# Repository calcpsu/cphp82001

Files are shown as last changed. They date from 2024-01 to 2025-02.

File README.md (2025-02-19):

# CalcPack HP 82001

A Li-Po battery replacement design for HP35/HP45/HP55/HP65/HP67 calculators. The original batteries had ~ 500mAh capacity, while modern Ni-MH replacements are typically ~1500mAh.

Li-Po has the advantage of far reduced self-discharge in comparison to Ni-MH, which is an advantage for an intermittently-used device. Even with similar mAh capacity, we can expect longer battery life.

Ni-MH / Ni-CD batteries are notorious for leaking. While Lithium Ion batteries are notorious for self-immolation, a well protected Li-Po battery (particularly in a low current application like this) should be able to be made very safe.

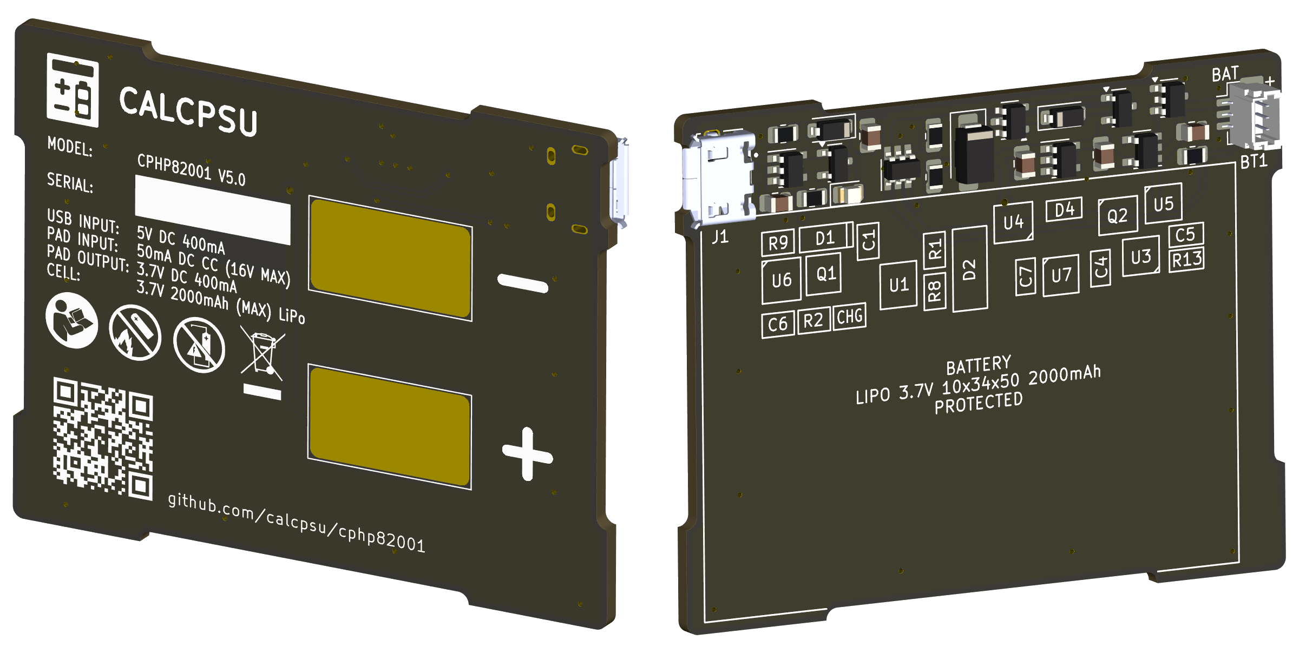
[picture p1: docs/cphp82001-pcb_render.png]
Render of calcpack PCB


## Features / design goals:
- Fit into existing compartment with no modifications
- Similar or ideally exceed capacity of standard Ni-Cd or Ni-MH 3xAA types (1200~2200mAh)
- Dual charge - USB (externally) or in-place using original HP charger
- Battery charge control and protection
- Maximise battery life:
    - Minimise Iq to maximise time between charges (shelf time)
    - Minimise voltage drop / series resistance of circuits to maximise run time
    - Optimise Vout to minimise calculator power consumption

## References 
This has been inspired by the below reference projects:
 - https://www.edn.com/classic-hp-35-calculator-comes-back-to-life/
   - GOOD: Regulated (see reasoning in the article, and discussion below)
   - BAD: Has no charging circuit / must remove to charge
   - BAD: Cannot connect HP charger (would cause dangerous overcharge condition; best case trip battery OC protection)
 - https://hackaday.io/project/175815-classic-hp-calculator-lipo-battery-pack
   - GOOD: Has on-board charge controller
   - BAD: Has no regulation
   - GOOD: Can connect HP charger, but
   - BAD: Unable to charge from HP charger / must remove to charge

## Key Components
If you're looking for a full BOM, please check the main files.
A digikey list is provided here for convenience (no guarantees!): [calcpsu cphp82001](https://www.digikey.com.au/en/mylists/list/Z6K09H5IB0)
 - Battery:
     - 10x34x50mm lipo pouch cell. These also include a DW01A/FS8205 protection circuit.
 - Charge controller: [BQ21040](https://www.ti.com/lit/ds/symlink/bq21040.pdf)
     - Wide voltage input range (over voltage protected)
     - Clever voltage foldback mode (which will help with constant current supply charging)
     - Variable current setting
     - Safety timer (10h) and 10% termination current
 - OPTION 1: Regulator: [TLV75801](https://www.ti.com/lit/ds/symlink/tlv758p.pdf)
     - Ultra low dropout (~30mV)
     - 500mA current limited (enough for HP67 card read/write at ~400mA for a few seconds)
     - Very low Iq for a regulator (25uA at idle, assuming Vb > Vo; only 400uA or so at full current)
     - Note: option eliminated as of REV5; if you're really keen for a regulated version please to check out rev4.
 - OPTION 2: Current Limiter: [MCP380SNT](https://www.onsemi.com/pdf/datasheet/ncp380-d.pdf)
     - Designed as a USB input current limiter, also works for LiPo cell voltage range
     - 800mA limiting, short circuit protection
     - Provides the similar current limiting capability as the TLV75801 with minimal additional quiescent current; allows retaining this function/protection in case of an unregulated option.
 - Output protection diode: [MAX40203](https://www.analog.com/media/en/technical-documentation/data-sheets/MAX40203.pdf)
     - Low voltage drop (~40mV) ideal diode
     - Low leakage and low Iq (<0.5uA)
 - Undervoltage protection: [APX809S-31SA](https://www.diodes.com/assets/Datasheets/APX809S-810S.pdf)
     - Pre-set with 3.1V threshold
     - Output used to shutdown regulator, shutting off load and vastly reducing Iq
     - Actual protective disconnection of battery done at ~2.5V by battery pack protection circuit (typically DW01A/FS8205)
 - Input overvoltage protection: [NCP360SNT](https://www.onsemi.com/pdf/datasheet/ncp360-d.pdf)
     - Cuts off USB input for overvoltage condition (note that 2x rated voltage is required by compliance test standard EN38.3 T.7, required for transport of lipo batteries in USA/EU).
     - Input via pads does not require OVP - it can tolerate the required 22v/100mA required condition.

## Function Description
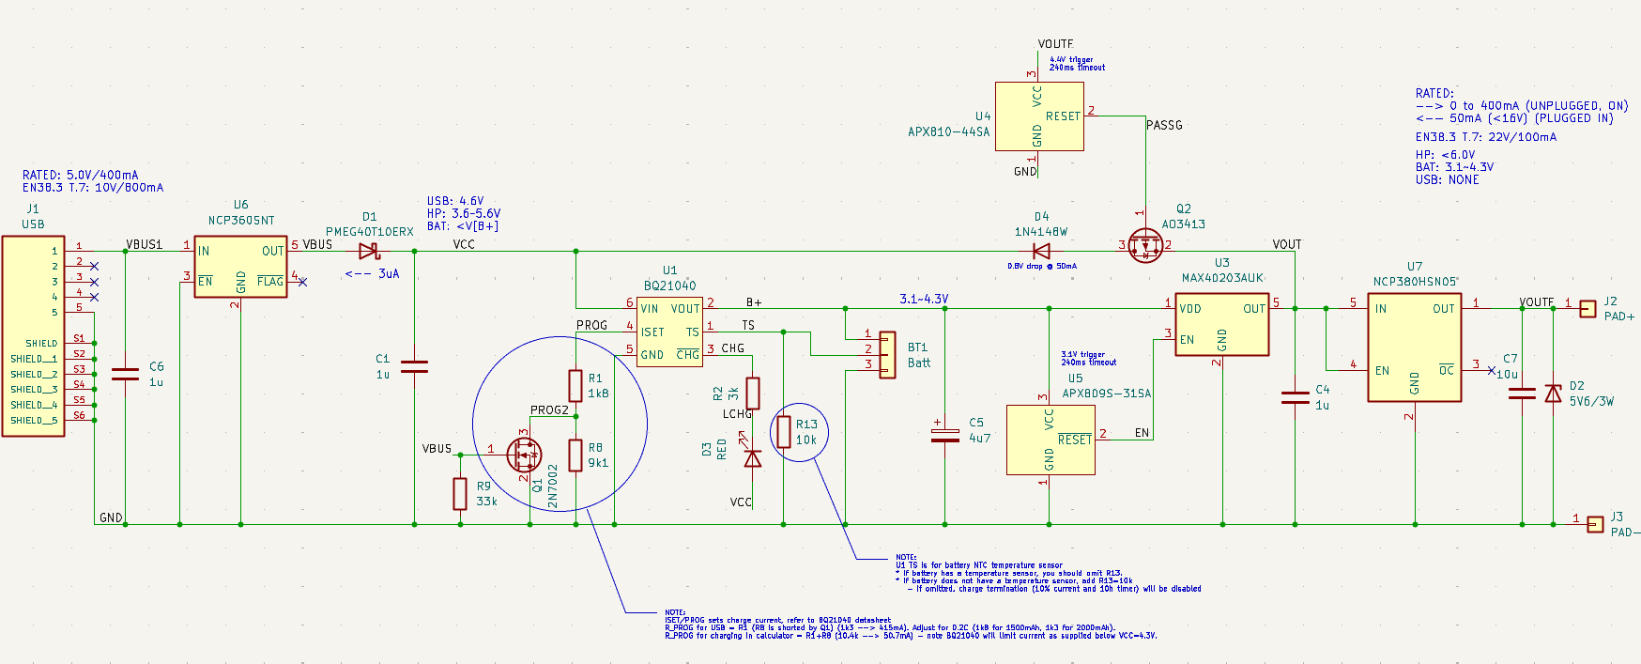
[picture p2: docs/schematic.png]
Block diagram of battery

### Discharging, calculator on:
 - B+ supplies cell voltage via current limiting IC
 - Output delivered to calculator via ideal diode U3
 - Vout at 3.8V is below threshold for U4 (4.4V), Q2 is off and VCC is 0V (charging IC shutdown completely)
### Charging, USB:
 - VBUS supplies VCC via U6 and D1
 - Presence of VBUS pulls prog down via Q1, charge controller now charges battery at higher current (0.2C target)
 - Physically not possible to do inside the calculator, can assume calculator is not connected during charging.
   - Although, body diode of Q2 and U3 would enable effective load sharing in this case, with output at about 4V (still well within acceptable limits for the calculator). This could be used for a future alternative in-system charging connection (e.g. a modified charging circuit, wireless charging, etc.)
### Charging, HP charger:
 - HP charger supplies 50mA constant current, up to 16V (!!). With the original NiCads, these acted as a voltage clamp (float charge about 1.43V/cell = 4.3V) - we need to replace this function.
    - With no charging current, voltage Vout rises until U3 switches off.
    - Will continue to rise until clamped by D2 (this should be low enough to protect HP65/67 sense chip from harm with extended application, but too low will result in excessive Iq as the voltage nears the zener's knee). Reviewing available documents, 4.3V is definitely OK, 6.25V might be survivable (as this is Vss normally). I have tested with 5.6V zener, and this has shown no negative impact to any calculators (particualrly the HP-67, where the sense chip sees this voltage, albeit when off).
    - Exceeding 4.4V for 240ms, U4 activates and connects Vout to Vcc via Q2 and D4.
    - D4 ensures that U1 throttles current (Vcc below 4.3V) before U4 cuts off supply (VOUTF 4.4V), maximising utilisation of limited constant current supply. See further explanation in [issue #5](https://github.com/calcpsu/cphp82001/issues/5).
    - U1 begins charge cycle, delivering up to 50mA to battery.
    - On charge termination, VCC current is minimal (10's of uA), all 50mA will be running through D2 (~0.25W power; using biggest one I can fit to keep temperature down). Voltage will be at the zener voltage (5.6V).
 - HP35/45/55 calculators do not draw current when on - supplied separately by HP AC adapter, the calculator supply is physically disconnected from the charging circuit.
 - HP65/67 with card reader: card reader may draw from battery supply. The sense chip is connected to the battery continuously, and will see up to the 5.6V float voltage. In case the calculator is operated and this draws current, the CC supply voltage will drop until U4 shuts off current to the charge circuit, resetting the charge cycle. When VOUT drops below B+, U3 activates, and card reader is powered from the current limiter (B+). As the AC adapter is not sufficient to run the card reader, this is the least worst outcome available.
### Battery Exhausted:
 - HP35 shows low battery (decimal points) indication at V+ of 3.50V.
   - This represents about 6-7% charge state of LiPo
   - User may switch off and recharge now...
 - HP67 will show indicator at about 3.60V; similar to above but a little more margin.
 - HP35 will cease to function at ~3.25V, still draws ~75mA
   - User probably should switch off and recharge now...
 - U4 protects battery at VB+ = 3.1V, by disabling the regulator or current limiting IC. Iq should be ~10uA.
 - If left for a _really_ long time, VB+ may reduce to 2.5V, which should trigger battery pack protection circuit and fully disconnect the battery. Plugging in (turning on charge controller, which will do a battery detection routine and reset the protection circuit) will reset.

## Assembly Notes ##

Refer to the schematic for details. The following notes are worth considering if building your own:
* The design up to v4 allows either regulated or unregulated option. From v5, only unregulated is supported (and recommended, see below).
  - For regulated (best for HP35), U2 regulator provides regulation and current limiting - U7 is not required and can be omitted and bypassed.
  - For unregulated (best for all later types), U2 is omitted and bypassed, and U7 is added to provide current limiting
* Digikey list is [here](https://www.digikey.com.au/en/mylists/list/Z6K09H5IB0)
* A 3-pin JST-SH (1.0mm pitch) connector is used for the battery. 1=pos, 2=temp, 3=neg
  - R13 is in parallel with TS pin NTC thermistor. If the battery does not a provide NTC thermistor (white wire, 3 pin connector), leave pin2 open and install R13=10k.
  - Note datasheet indicates 237k resistor prevents timer disable mode, but this also prevents charging without thermistor
    
| R13 | Battery With Temperature Sensor | Battery Without Temperature Sensor |
| --- | --- | --- |
| Omit | 🟢 10% Current Charge Termination <br> 🟢 10h Charge Timeout | 🔴 10% Current Charge Termination <br> 🔴 10h Charge Timeout |
| 10k  | ⚠️ Will not charge T>25C <br> ⚠️ Will charge T<0C  | 🟢 10% Current Charge Termination <br> 🟢  charge timeout |

* Two case sizes are provided:
    * 8mm suits 8mm thick batteries (1500mAh)
    * 10mm suits 10mm thick batteries (2000mAh), but it has been noted this can be a tight fit in some calculators
* Variants of each case, with and without an LED hole, are provided. If you 3D print with a transluscent material, the hole is not needed!

## Notes on optimisation:

Addition of a series regulator is not an immediately obvious means to maximise efficiency. I've measured the HP-35 increases current consumption as voltage rises (this is most likely a result of the way the LEDs are driven with fixed-duty inductive energy, this appears as brighter leds). Even accounting for the linear loss and Iq of the regulator circuit, total power consumption decreases as the regulator voltage decreases (down to about 3.6V, the minimum to operate the calculator reliably). The newer models (HP-45, HP-67) do the opposite - the current drops as the voltage increases, which indicates a more typical profile for a switchmode converter. The HP-67 has a card reader with a motor; this draws around 400mA when reading/writing a card, direct from battery. To allow for a little drop in the system, the regulator voltage needs to be a touch higher (looks like about 3.8V works consistently).

### Why not a switching regulator?

In theory, replacing the series linear regulator with a switching regulator may allow use of the battery capacity right down to 3.1V, and more efficiently use the currently wasted energy of the full battery (VB+ > 3.78V) currently being dissipated by the linear reg.

I've investigated using a MIC2250 step-up regulator, which has a surprisingly low Iq (55uA, not switching), and could provide a consistent output voltage right down to the end of the battery capacity (Vb=3.0V). At the currents needed, this can be around 87% efficient. This would provide a consistent voltage right up until shutdown. While this might be good particularly for the HP-67 card reader, it has the disadvantage of skipping the calculator's built-in low battery indication - the power supply unit would completely shutdown without any warning with a low battery.

### Model of 3 options

I've done a simulation of the 3 options:

  1. No regulator (default - calculator supplied with battery voltage via MAX40203 diode)
  2. Linear regulator (TLV75801, set to 3.80V)
  3. Switchmode step-up regulator (MIC2250, set to 3.80V also)

For each, the model calculates the change in output voltages given the battery state, calculator and power supply current draw, and iterates until the battery (2000mAh) is exhausted. The calculator load is measured from 3 sample calculators (HP-35, HP-45 and HP-67), reflecting the calculator being left on in the default display ("0." or "0.00" depending on the model), and accounts for the changing current with changing supply voltage. Results are shown below.

In summary, a regulated design gains a slight advantage in run time for the HP-35, while slightly reducing run time for HP-45 and HP-67. The switchmode design is actually best for the current-hungry HP-67, but not by a significant amount, and at the cost of higher quiescent current (shortening standby time significantly).

In conclusion, the regulated design provides a slight advantage for the HP-35 based on this model, however the unregulated design (with addition of necessary output short-circuit protection / current limiter) can be expected to be ideal for other models. Prototype testing with rev 3.5 showed the unregulated design works well in all the calculators, and the regulated design had noticeably faster self-discharge in practice, particularly as the quiescent current is larger than anticipated in dropout mode. As such, further designs have eliminated the regulator in favour of improved board layout and ease of use.

#### Results summary (t in hours)
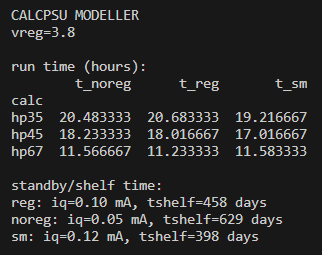
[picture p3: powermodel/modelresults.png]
Image of power model results

#### HP-35
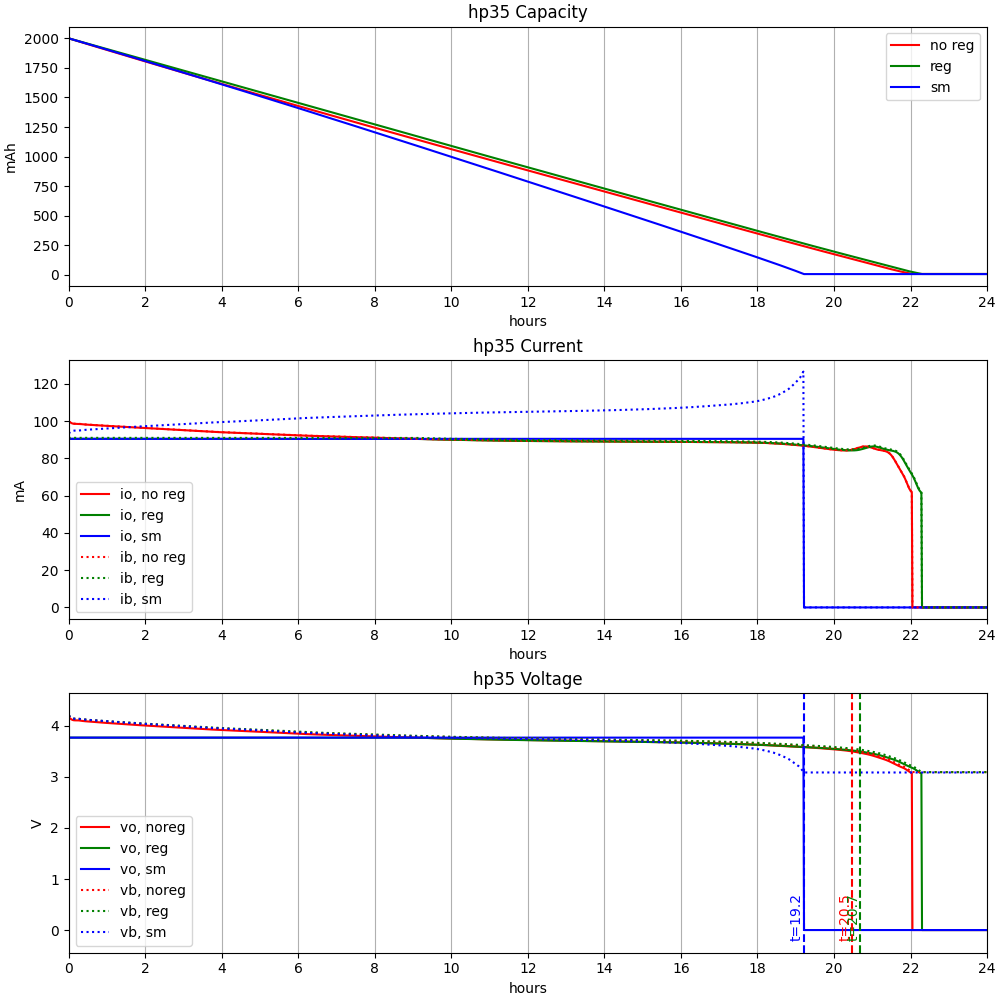
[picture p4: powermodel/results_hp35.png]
Image of power model results

#### HP-45
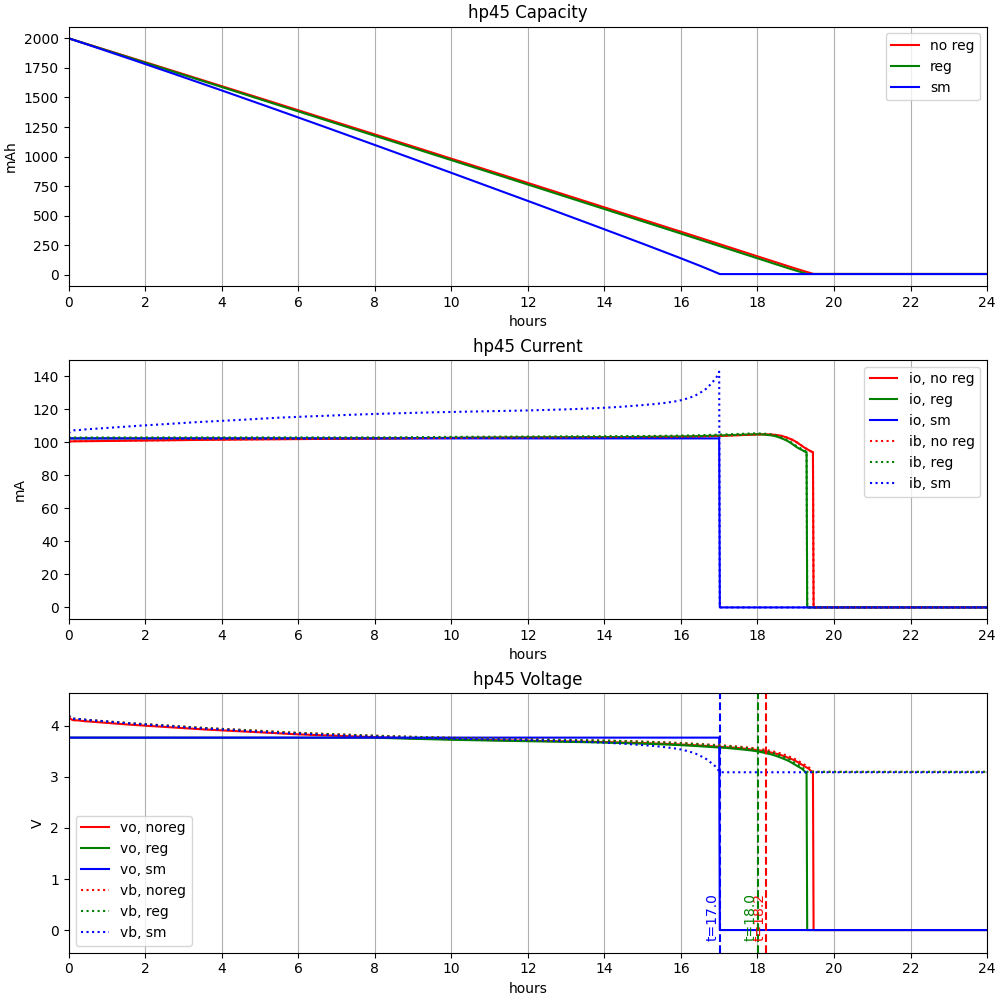
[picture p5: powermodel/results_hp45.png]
Image of power model results

#### HP-67
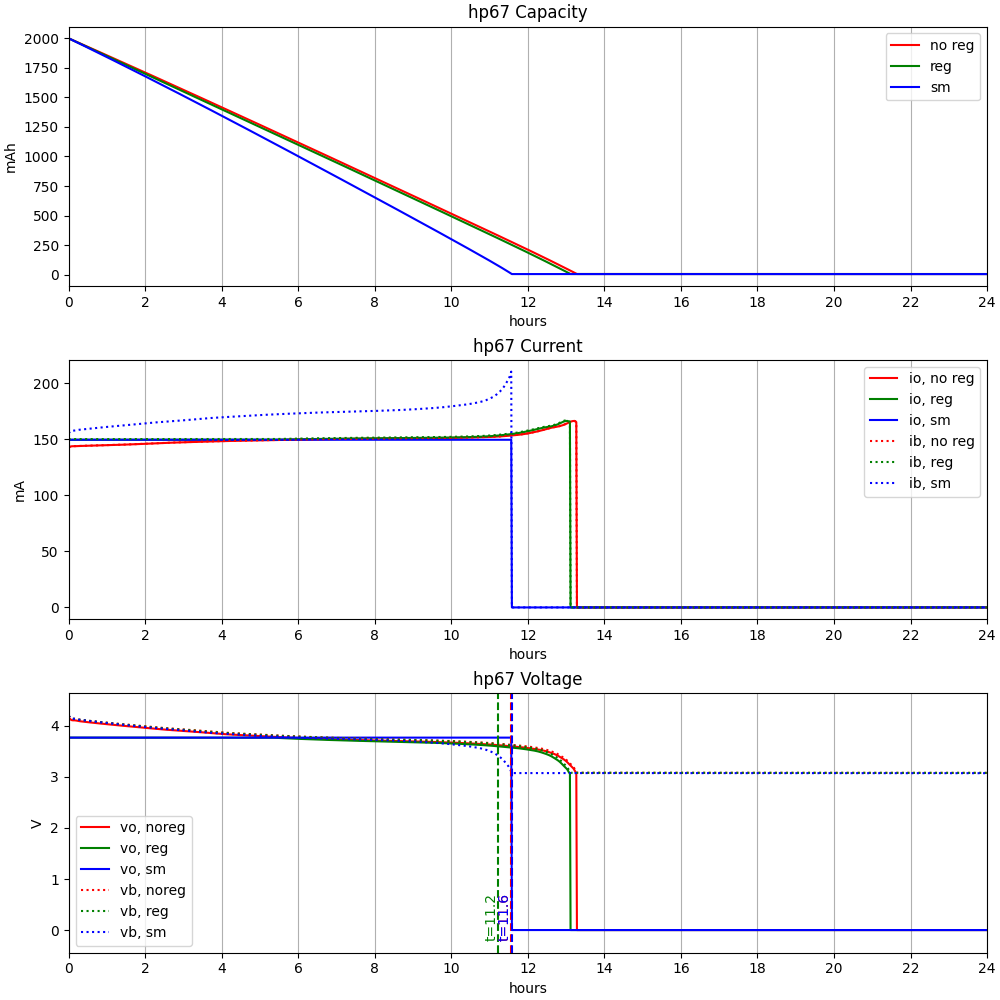
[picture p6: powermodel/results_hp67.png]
Image of power model results


## Community Builds ##
Built one? Send me some pics and I'll share here!
### [Milo van der Zee](https://github.com/MilovdZee) ###
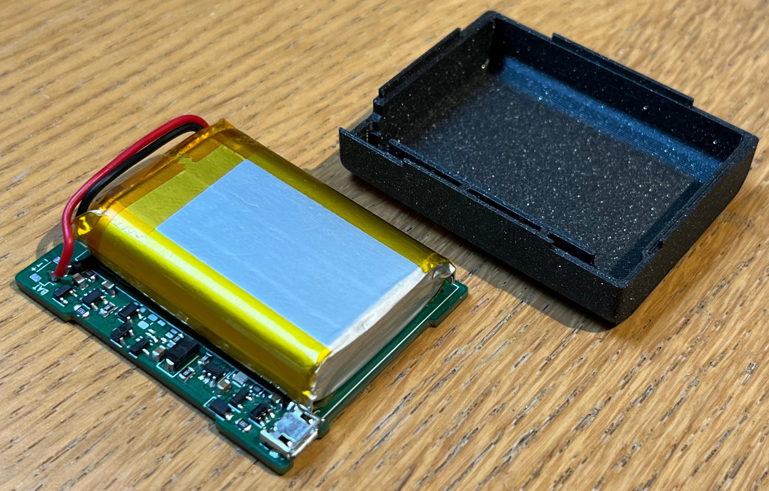
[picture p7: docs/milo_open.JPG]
Photo of build by Milo van der Zee


## License

This work is licensed under a
[Creative Commons Attribution-NonCommercial-ShareAlike 4.0 International License][cc-by-nc-sa].

[][cc-by-nc-sa]

[cc-by-nc-sa]: http://creativecommons.org/licenses/by-nc-sa/4.0/
[cc-by-nc-sa-image]: https://licensebuttons.net/l/by-nc-sa/4.0/88x31.png
[cc-by-nc-sa-shield]: https://img.shields.io/badge/License-CC%20BY--NC--SA%204.0-lightgrey.svg

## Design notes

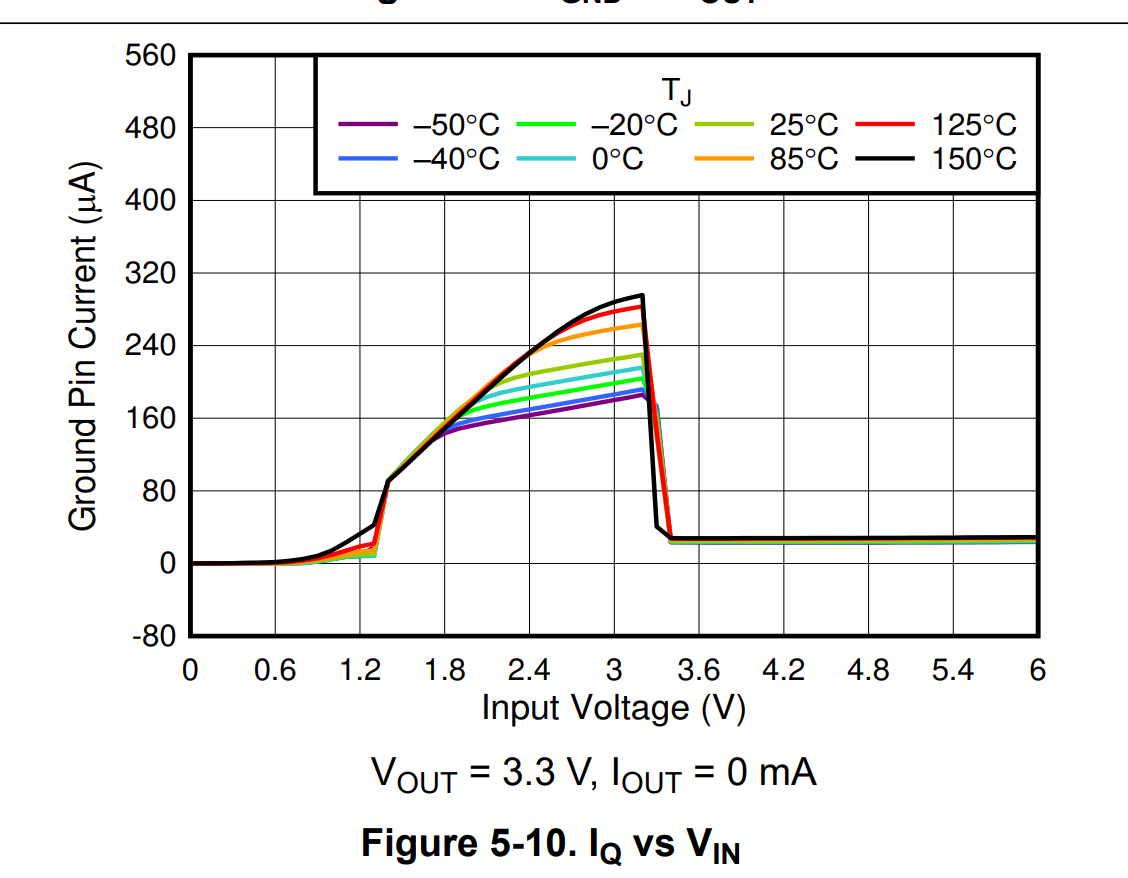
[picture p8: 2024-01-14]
powermodel/tlv75801_iq_3v3.png

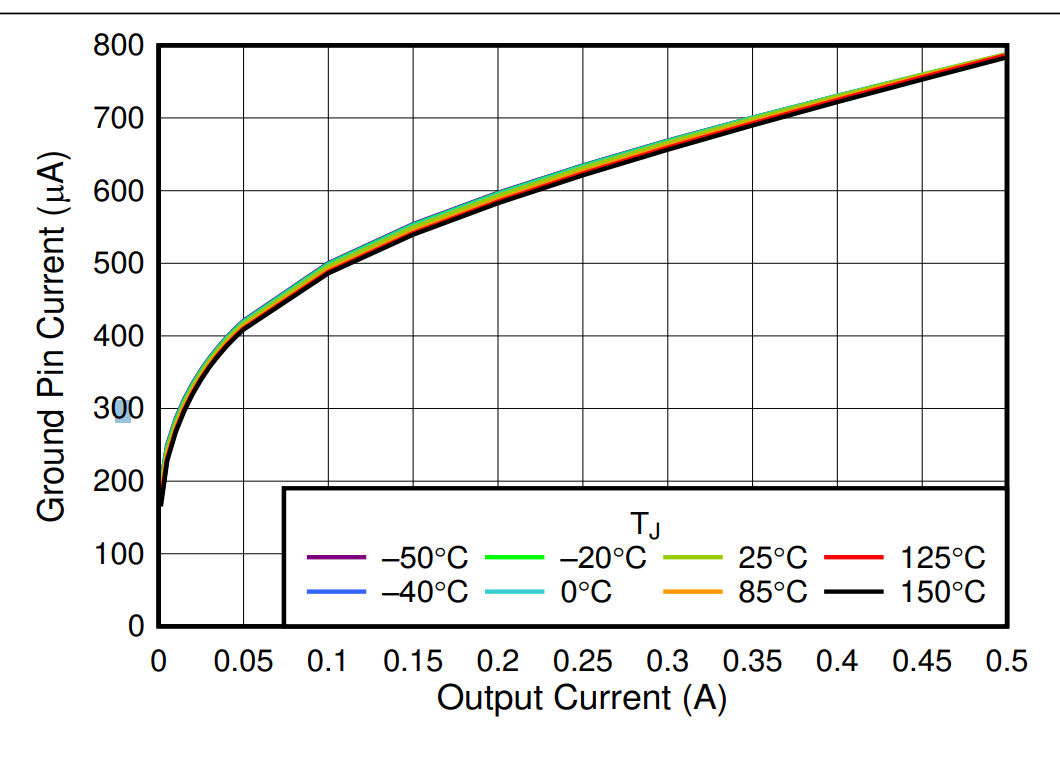
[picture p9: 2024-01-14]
powermodel/tlv75801_ignd.png

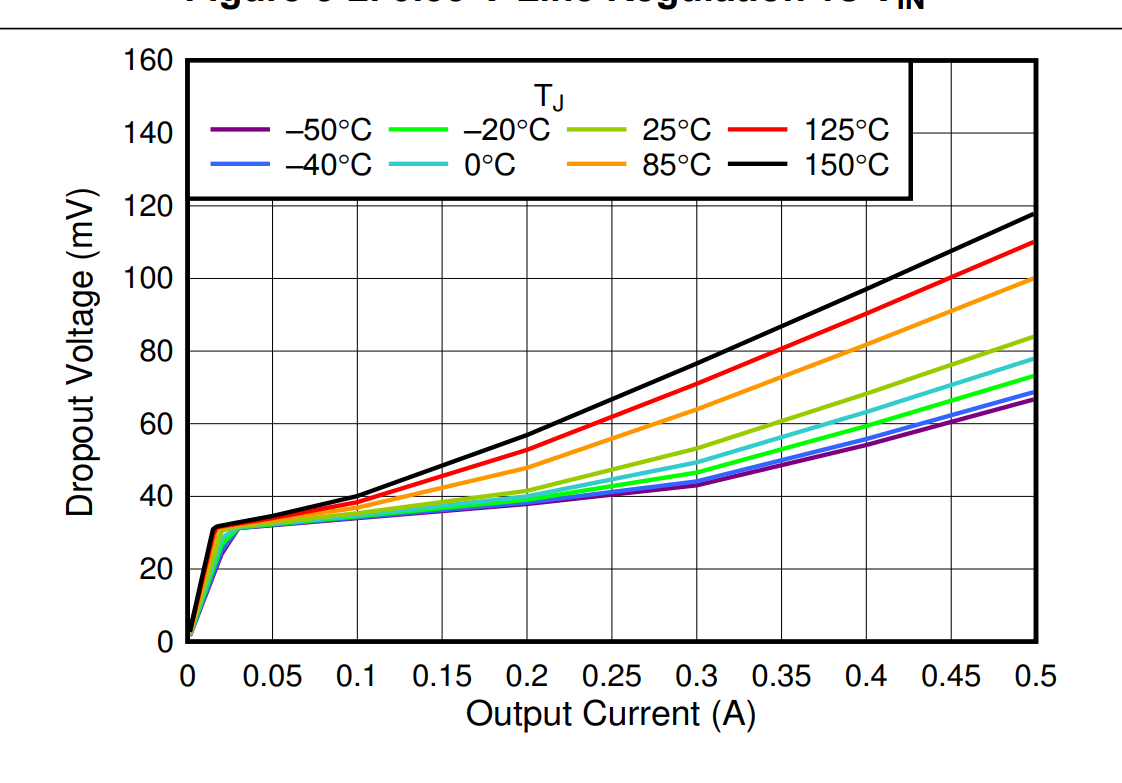
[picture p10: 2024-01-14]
powermodel/tlv75801_vdo.png

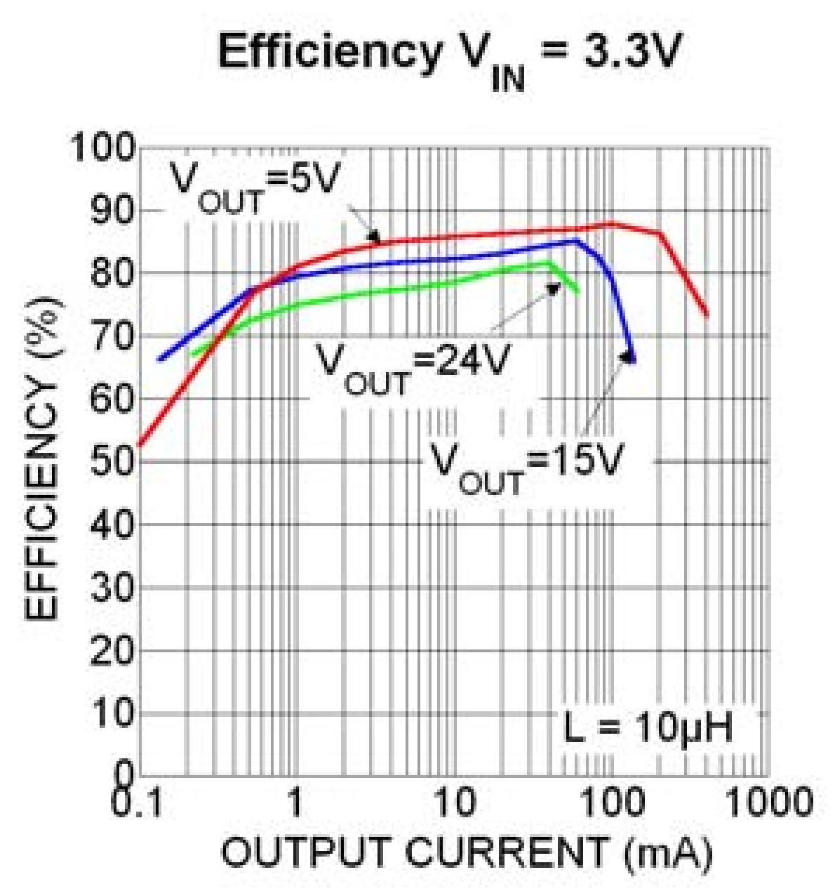
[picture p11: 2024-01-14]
powermodel/mcp2250_efficiency.png

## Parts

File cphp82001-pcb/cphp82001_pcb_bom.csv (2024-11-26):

Reference | Value | Datasheet | Footprint | Qty | DNP
BT1 | Batt | ~ | george:JST_SH_BM03B-SRSS-TB_1x03-1MP_P1.00mm_Vertical_13PADS | 1
C1,C4,C6 | 1u | ~ | Capacitor_SMD:C_0805_2012Metric | 3
C5 | 4u7 | ~ | Capacitor_SMD:C_0805_2012Metric | 1
C7 | 10u | ~ | Capacitor_SMD:C_0805_2012Metric | 1
D1 | PMEG40T10ERX | http://www.vishay.com/docs/88525/1n5817.pdf | Diode_SMD:D_SOD-123 | 1
D2 | 5V6/3W | ~ | Diode_SMD:D_SMA | 1
D3 | RED | ~ | LED_SMD:LED_0805_2012Metric | 1
D4 | 1N4148W | https://www.vishay.com/docs/85748/1n4148w.pdf | Diode_SMD:D_SOD-123 | 1
J1 | USB |  | mod_local:AMPHENOL_10118194-0001LF | 1
J2 | PAD+ | ~ | george:PAD_8x15 | 1
J3 | PAD- | ~ | george:PAD_8x15 | 1
Q1 | 2N7002 | https://www.onsemi.com/pub/Collateral/NDS7002A-D.PDF | Package_TO_SOT_SMD:SOT-23 | 1
Q2 | AO3413 | http://www.aosmd.com/pdfs/datasheet/AO3401A.pdf | Package_TO_SOT_SMD:SOT-23 | 1
R1 | 1k8 | ~ | Resistor_SMD:R_0805_2012Metric | 1
R2 | 3k | ~ | Resistor_SMD:R_0805_2012Metric | 1
R8 | 9k1 | ~ | Resistor_SMD:R_0805_2012Metric | 1
R9 | 33k | ~ | Resistor_SMD:R_0805_2012Metric | 1
R13 | 10k | ~ | Resistor_SMD:R_0805_2012Metric | 1
U1 | BQ21040 | https://www.ti.com/lit/ds/symlink/bq21040.pdf | george:SOT-23-6_TI_DBV6 | 1
U3 | MAX40203AUK | https://datasheets.maximintegrated.com/en/ds/MAX40200.pdf | george:SOT-23-5_TI_DBV5 | 1
U4 | APX810-44SA | https://www.diodes.com/assets/Datasheets/APX803S.pdf | Package_TO_SOT_SMD:SOT-23-3 | 1
U5 | APX809S-31SA | https://www.diodes.com/assets/Datasheets/APX803S.pdf | Package_TO_SOT_SMD:SOT-23-3 | 1
U6 | NCP360SNT | https://www.onsemi.com/pdf/datasheet/ncp349-d.pdf | george:SOT-23-5_TI_DBV5 | 1
U7 | NCP380HSN05 | http://www.ti.com/lit/ds/symlink/tps2041.pdf | george:SOT-23-5_TI_DBV5 | 1

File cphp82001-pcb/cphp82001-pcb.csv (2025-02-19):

Id | Designator | Footprint | Quantity | Designation | Supplier and ref
1 | Q2 | SOT-23 | 1 | AO3413
2 | U7 | SOT-23-5_TI_DBV5 | 1 | NCP380HSN05
3 | D2 | D_SMA | 1 | 5V6/3W
4 | C5 | C_0805_2012Metric | 1 | 4u7
5 | D3 | LED_0805_2012Metric | 1 | RED
6 | U6 | SOT-23-5_TI_DBV5 | 1 | NCP360SNT
7 | C7 | C_0805_2012Metric | 1 | 10u
8 | C6,C4,C1 | C_0805_2012Metric | 3 | 1u
9 | U1 | SOT-23-6_TI_DBV6 | 1 | BQ21040
10 | J1 | AMPHENOL_10118194-0001LF | 1 | USB
11 | R1 | R_0805_2012Metric | 1 | 1k8
12 | R8 | R_0805_2012Metric | 1 | 9k1
13 | R13 | R_0805_2012Metric | 1 | 10k
14 | U5 | SOT-23-3 | 1 | APX809S-31SA
15 | Q1 | SOT-23 | 1 | 2N7002
16 | U3 | SOT-23-5_TI_DBV5 | 1 | MAX40203AUK
17 | U4 | SOT-23-3 | 1 | APX810-44SA
18 | R2 | R_0805_2012Metric | 1 | 3k
19 | D4 | D_SOD-123 | 1 | 1N4148W
20 | BT1 | JST_SH_BM03B-SRSS-TB_1x03-1MP_P1.00mm_Vertical_13PADS | 1 | Batt
21 | R9 | R_0805_2012Metric | 1 | 33k
22 | D1 | D_SOD-123 | 1 | PMEG40T10ERX
23 | J3 | PAD_8x15 | 1 | PAD-
24 | J2 | PAD_8x15 | 1 | PAD+

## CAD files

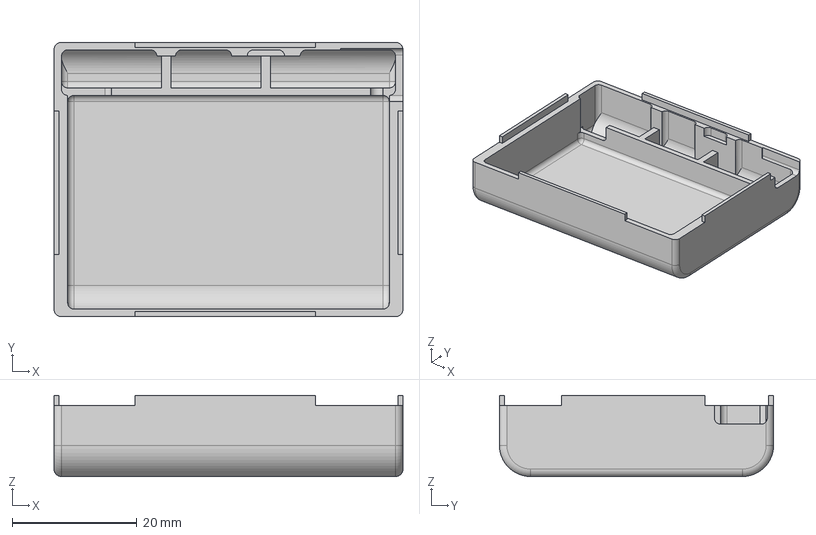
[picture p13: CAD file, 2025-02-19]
case/10mm battery/cphp82001_case_10mm.step
56.0 x 44.0 x 13.0 mm

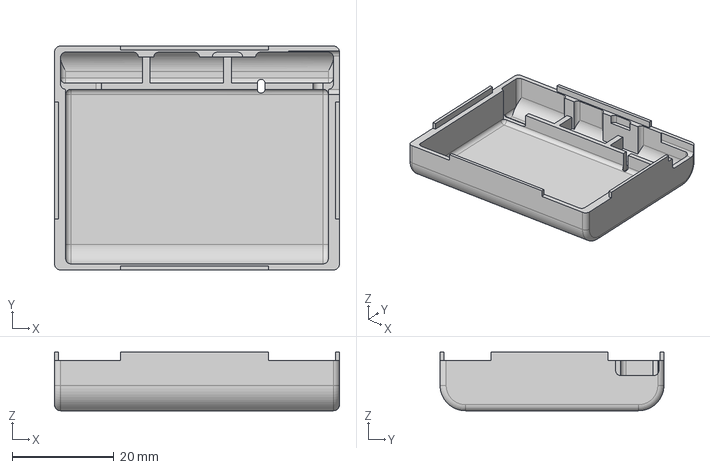
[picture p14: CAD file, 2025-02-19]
case/8mm battery/cphp82001_case_led_8mm.step
56.0 x 44.0 x 11.5 mm

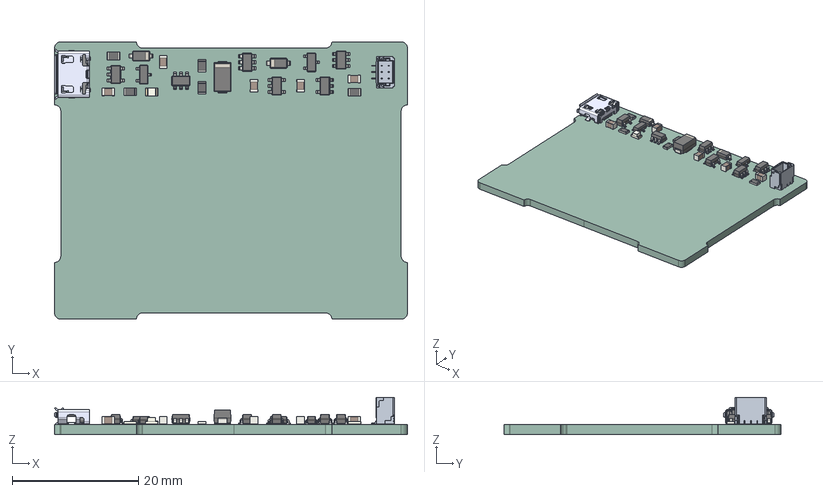
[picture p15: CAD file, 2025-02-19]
cphp82001-pcb/cphp82001-pcb.step
56.0 x 44.0 x 5.90 mm
SOT_23 x 2
SOT_23_5 x 3
D_SMA
C_0805_2012Metric x 5
LED_0805_2012Metric
SOT_23_6 x 3
10118194-0001LF
R_0805_2012Metric x 5
D_SOD_123 x 2
BM03B-SRSS-TB
cphp82001-pcb_PCB

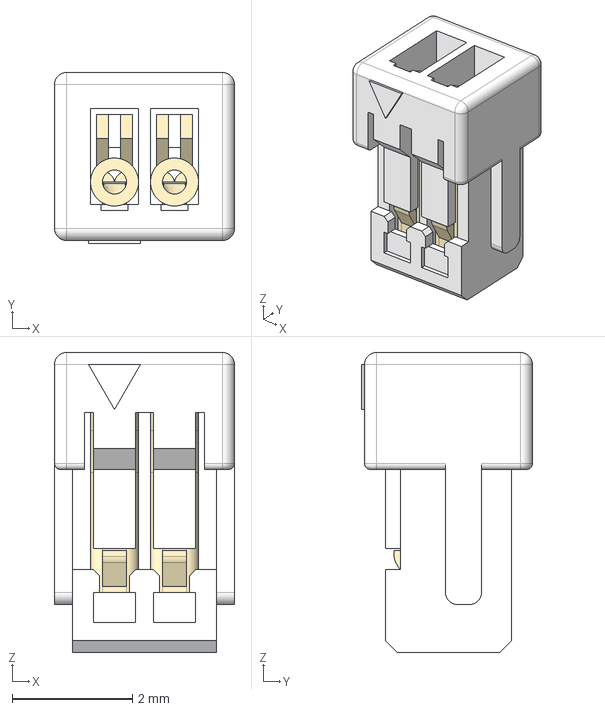
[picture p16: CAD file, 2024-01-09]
cphp82001-pcb/3d/SHR-02V-S.step
3.00 x 2.85 x 5.00 mm

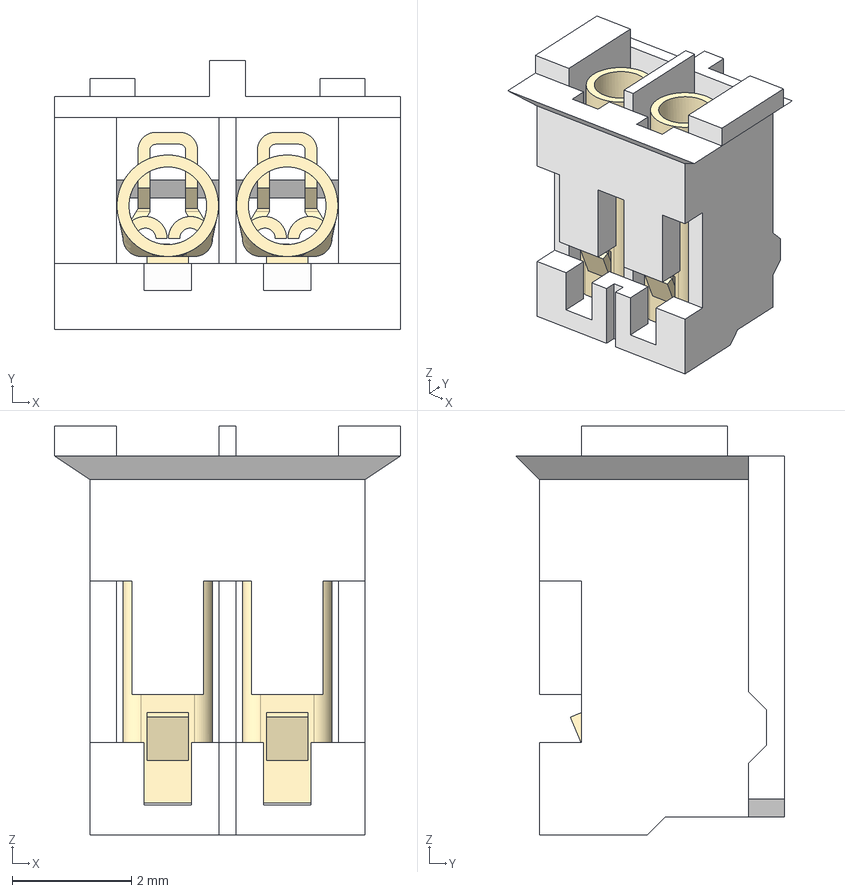
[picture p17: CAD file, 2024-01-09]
cphp82001-pcb/3d/PHR-2.step
5.80 x 4.50 x 6.85 mm

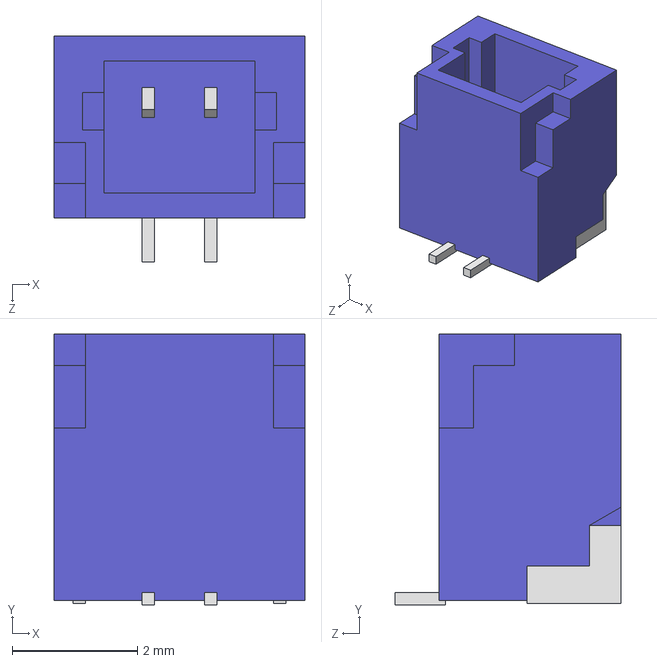
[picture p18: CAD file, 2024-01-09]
cphp82001-pcb/3d/BM02B-SRSS-TB.STEP
4.00 x 4.32 x 3.60 mm

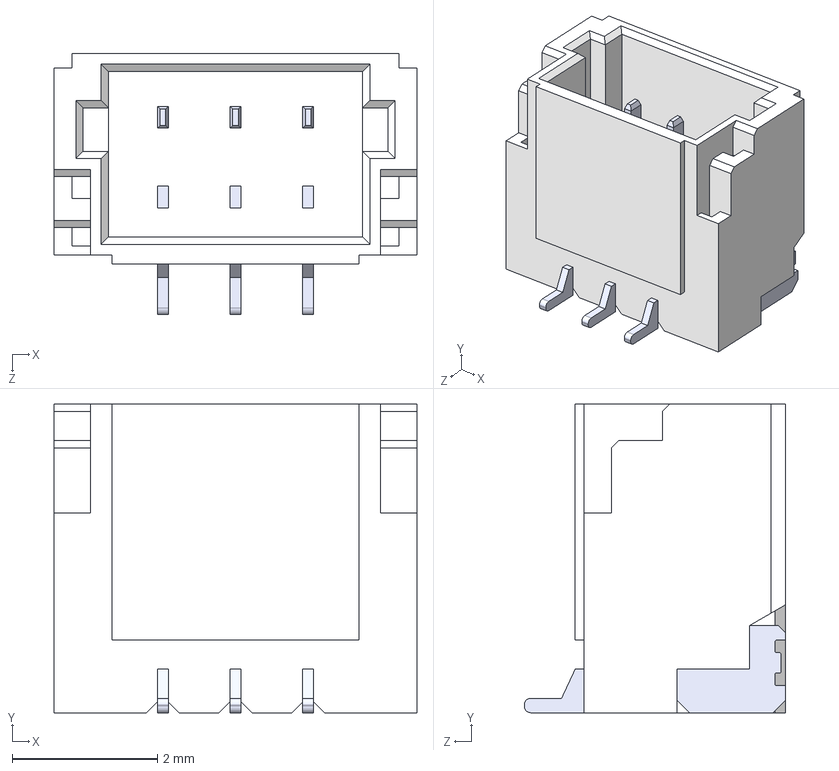
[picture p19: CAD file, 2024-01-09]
cphp82001-pcb/3d/BM03B-SRSS-TB.STEP
5.00 x 4.25 x 3.60 mm

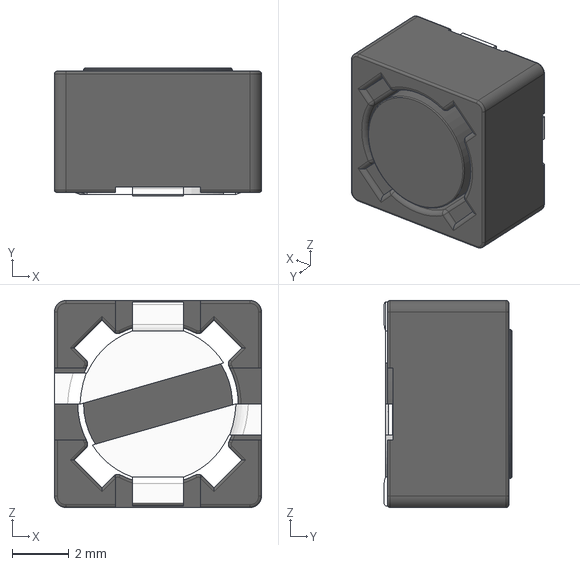
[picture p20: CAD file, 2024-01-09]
cphp82001-pcb/3d/CDRN74.stp
7.30 x 4.50 x 7.30 mm

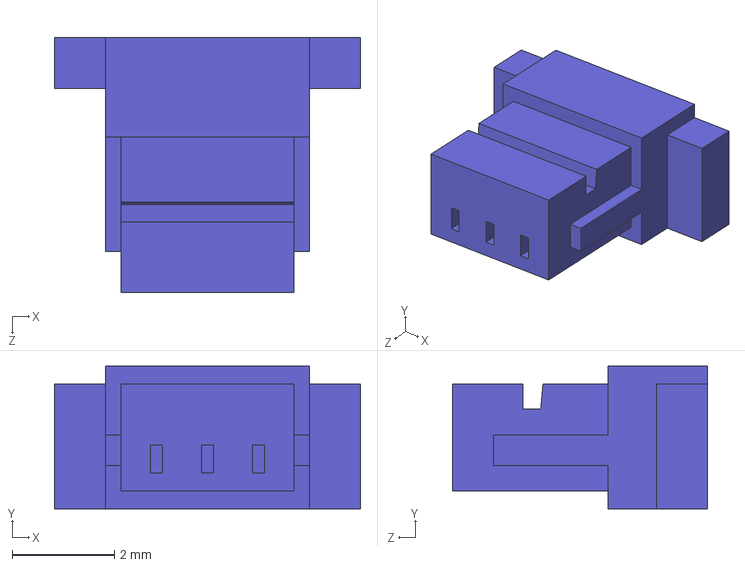
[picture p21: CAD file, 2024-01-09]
cphp82001-pcb/3d/SHR-03V-S-B.STEP
6.00 x 2.80 x 5.00 mm

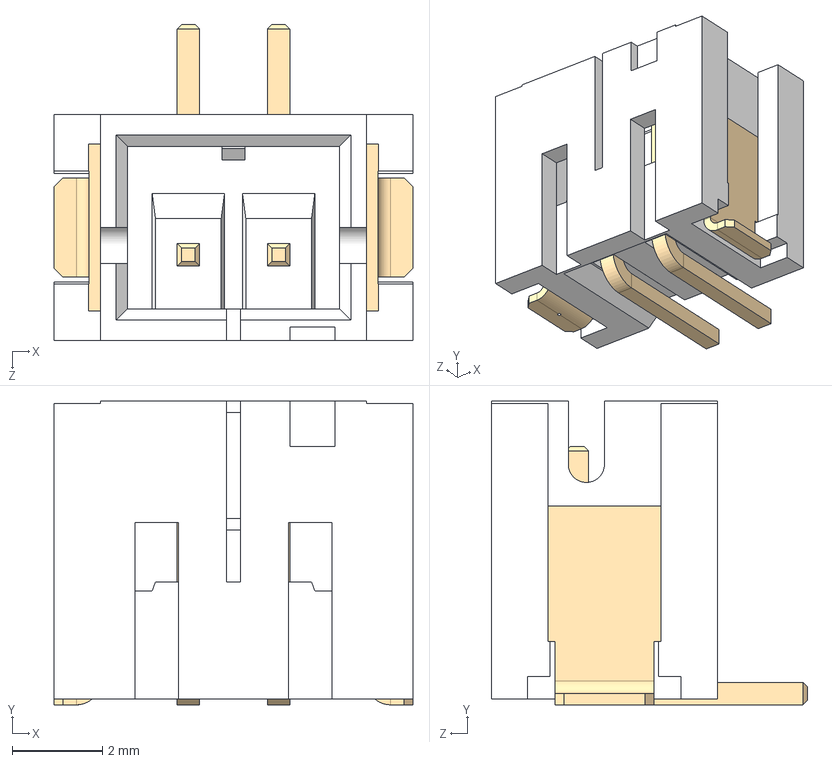
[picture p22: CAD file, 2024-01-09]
cphp82001-pcb/3d/JST-B2B-PH-SM4-TB.STEP
7.95 x 6.72 x 7.00 mm

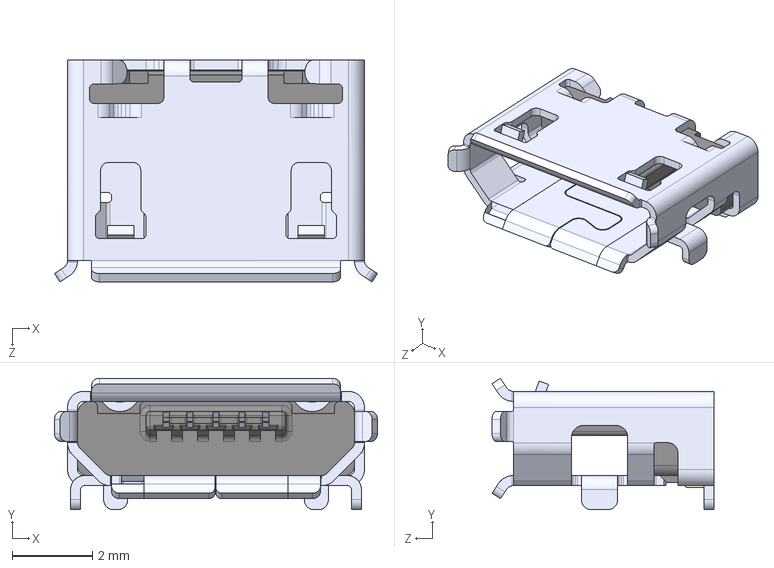
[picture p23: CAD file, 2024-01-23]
cphp82001-pcb/3d/10118194-0001LF.step
8.05 x 3.27 x 5.53 mm

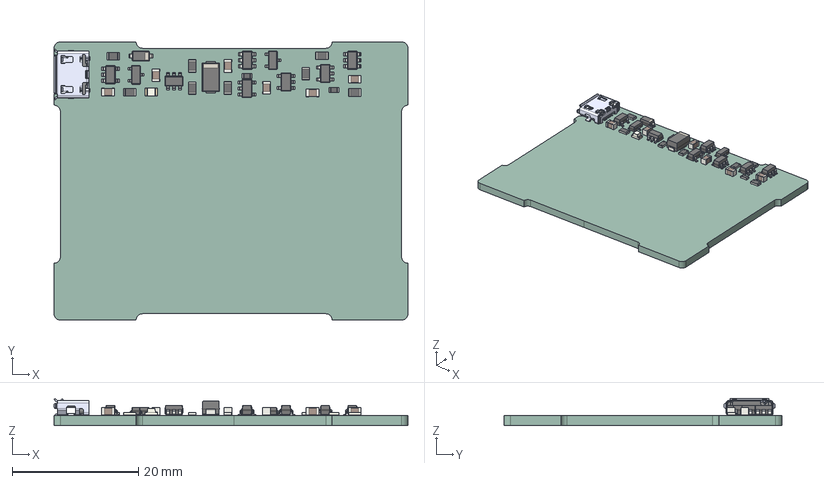
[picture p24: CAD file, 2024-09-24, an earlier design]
cphp82001-pcb/plot/rev4/cphp82001-pcb-rev4.step
56.0 x 44.0 x 4.32 mm
SOT_23 x 2
SOT_23_5 x 4
D_SMA
C_0805_2012Metric x 6
LED_0805_2012Metric
SOT_23_6 x 3
10118194-0001LF
R_0805_2012Metric x 8
R_0603_1608Metric x 2
D_SOD_123
cphp82001-pcb_PCB

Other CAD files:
cphp82001-pcb/plot/rev5/cphp82001-pcb-rev5.step
case/10mm battery/cphp82001_case_led_10mm.step
case/8mm battery/cphp82001_case_8mm.step
case/10mm battery/cphp82001_case_10mm.stl
case/10mm battery/cphp82001_case_led_10mm.stl
case/8mm battery/cphp82001_case_8mm.stl
case/8mm battery/cphp82001_case_led_8mm.stl

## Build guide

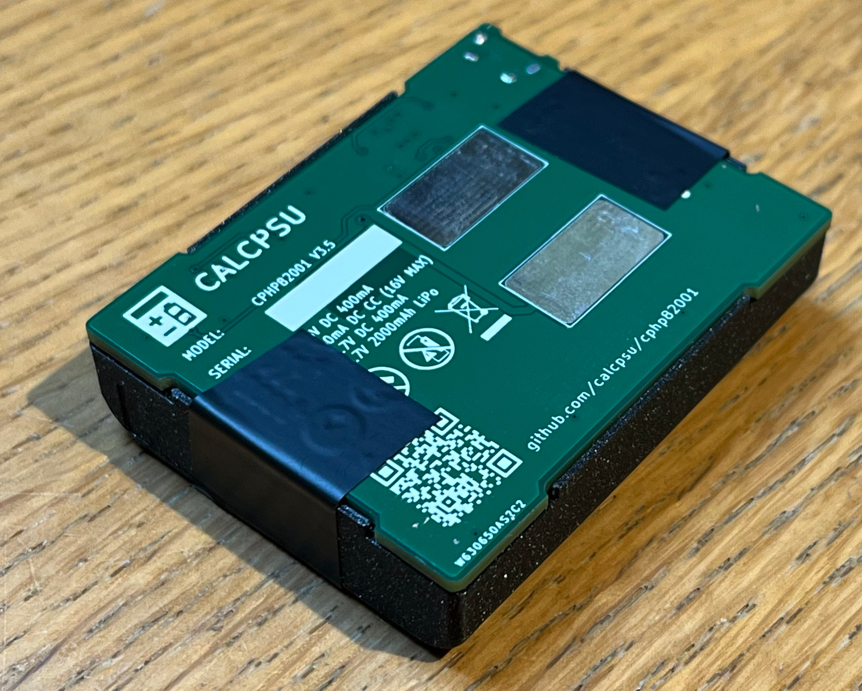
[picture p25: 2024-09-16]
docs/milo_assembled.JPG

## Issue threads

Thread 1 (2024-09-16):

JP1 is incorrect

grob6000, 2024-09-16:
JP1 is intended to help make an unregulated version. This should bridge U2 (B+ to VREG), not U3.
Workaround - to make an unregulated version, bridge input and output of U2 directly on the IC footprint (pin 5 to pin 1).

grob6000, 2024-09-24:
Corrected with 2951f1485d85d3fa7d55ea8e0cb5fbce0e2f9556

Closed 2024-09-24.

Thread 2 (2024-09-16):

USB connector difficult to solder

grob6000, 2024-09-16:
Ground plane connection to USB connector is too strong; challenging to solder without excessive heating of board/plane.
Improve thermal relief for ground pin and shield.

MilovdZee, 2024-09-17:
Almost not possible to solder with an iron but went fine with my hot air station

grob6000, 2024-09-24:
Thanks for the feedback. I have adjusted the thermal relief of the USB in v4 - adjacent shield connections are thermally relieved from ground plane, and GND pin I've changed to a single connect. I'd argue micro usb connectors are always a bear to hand solder, but happy to improve AFAIRP. See 2951f1485d85d3fa7d55ea8e0cb5fbce0e2f9556

Closed 2024-09-24.

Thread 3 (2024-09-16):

Alternative battery connection

grob6000, 2024-09-16:
For others building who don't want to use the tiny JST-SH connector for the battery, should add a small wire connection for battery.

MilovdZee, 2024-09-17:
And why bother with a connector? My battery had a different connector anyway so I just soldered the wires directly on the board. Larger pads would indeed be nice.

grob6000, 2024-09-24:
I included the connector as I prefer to be able to add/remove the battery for testing.
* I've connected the battery +/- to the mechanical pads on the connector and made them a bit larger again, for doing what you've done. Great suggestion. No through-holes, as I don't want the B+ to be able to be contacted from the back. See 2951f1485d85d3fa7d55ea8e0cb5fbce0e2f9556.
* If there is no temperature sensor on the battery, then either populate R13 10k (battery normal charge with 10h shutdown, this is safest and what I like to build), or omit R13 - leaving TS floating (i.e. omit R13) or high (you can short pin2 and B+ on the connector) enables TTDM which disables 10h timeout. Refer to [datasheet](https://www.ti.com/lit/ds/symlink/bq21040.pdf). Note added to schematic: 7d6d5fe98b52145ec4c7ec134e7c0ce91a6d1320

MilovdZee, 2024-09-24:
I misread VSS as being VCC. But VSS is GND and so the 10k resister is perfect already. Thanks

Closed 2024-09-24.

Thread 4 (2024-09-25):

R1 and R8 values differ between schematics and BOM

MilovdZee, 2024-09-25:
It does not really matter but it is just inconsistent.

Also from the specs: Programs the Fast-charge current setting. External resistor from ISET to VSS defines fast charge
current value. Range is 10.8kΩ (50mA) to 675Ω (800mA).

So the 11k resister exceeds the max value. The BOM value of 10k is probably better.

I think you mean to set the values in the schematics also to 1k3 and 10k. That at least is consistent with the specs and the BOM.

grob6000, 2024-09-26:
The BOM was outdated; I've re-run direct from KICAD and it should now match the v4 schematic (0dc3c41eb4f7892238718d715c050627dc70e223). Thanks for spotting.

R1=1.8k provides USB charging current of 540/1.8 = 300mA, which is an ideal safe charge current of 0.2C for a 1500mAh battery
R1=1.3k would be 415mA, which is close to 0.2C for a 2000mAh battery.

R1+R8 sets the charge current when connected to the HP original charger (in-system). This is more the critical value. I know the datasheet says 10.8k max (50mA min), but hear me out:

The original HP charger supplies 50mA constant current (mine does 49.5mA pretty consistently, I'd be keen to collect more data but given the simple 2 transistor design I'm surprised it's better than +/-2mA).

When the 50mA supply is fed to the pads, the voltage will rise to above B+, and U3 will switch off, preventing this from directly feeding B+ - great. Note that U7 (NCP380) does not prevent backfeed (acts like a diode), so when the pad voltage exceeds 4.4V, U4 will switch on, and connect the pads to VIN of the U1 (BQ21040) via Q2 and U7 (which might be bypassed, if using the regulated design). U1 then starts up and charges the battery at ISET.

* If the total current consumed exceeds what the supply provides (>50mA), then the supply voltage will drop. While U1 will throttle current if the voltage drops below 4.3V (can maintain down at least as far as 3.5V), U4 will switch off at VOUTF=4.4V; prior to any throttling occurring. U4 has a 240ms reset timer, so the effect is a 240ms oscillation (flashing red CHG light). With U7 present, the ~0.3V body diode drop will help a little, but
* If the total current consumed is less than the supply current (<50mA), then the charging works as normal, and the input voltage is regulated by the 5.6V zener.

I did consider relying on the BQ20140 current throttling (i.e. by replacing Q2 with a diode), however this means the charging IC is powered even when the battery is idle. In this case, it will not meet the power good threshold, and stay in standby mode. However, standby current is 125uA. In comparison, U4 consumes 30uA only. The 4.4V threshold must be above the charging output voltage (4.28V max).

Therefore, it's kind of critical that ISET is low enough that the total current draw does not exceed the constant current input supply, such that a small margin is available to run through the 5.6V zener and maintain the pad voltage >4.4V. Using the table below, even 12.8k is marginal.

| R1 | R8 | R1+R8 | ISET <br> MIN <br> KISET=470 | ISET<br>Nominal<br>KISET=527 | ISET<br>Max<br>KISET=605 | Recommend? |
| -- | -- | -- | -- | -- | -- | -- |
| 1.8k | 10k | 11.8k | 🟢 39.8mA | 🟢 44.7mA | 🔴  51.3mA |  |
| 1.8k | 11k | 12.8k | 🟢 36.7mA | 🟢 41.2mA | 🟠 47.3mA | ✔️|
| 1.3k | 10k | 11.3k | 🟢 41.6mA | 🟠 46.6mA | 🔴 53.5mA | |
| 1.3k | 11k | 12.3k | 🟢 38.2mA | 🟢 42.8mA | 🟠 49.2mA | ✔️ |

Note the datasheet does provide KISET values for 25~60mA (and lower!):
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

Now you've made me look at it again, I could in theory put 1V of diode between Q2 pin 3 and VCC, such that the idle voltage of 5.6V meant 4.6V at VCC (plenty for a 50mA charge), and at the cutout of VOUTF=4.4V, VCC was 3.4V - which would let U1 current throttle as designed, and thus the ISET could be 50mA (so 9.1k would work), and charge would be 20% faster.

MilovdZee, 2024-09-27:
Wow, a very comprehensive answer :) I'll study it :)

grob6000, 2024-10-15:
R1 and R8 values revisited for v5: 30ffbc13f589585e5461ab38b471176c49de2603

Closed 2024-10-15.

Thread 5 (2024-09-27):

Insufficient current from HP power supply + low battery charge state = no charge / flashing CHG LED

grob6000, 2024-09-27:
Raised in https://github.com/calcpsu/cphp82001/issues/4#issuecomment-2375859775

If current consumption exceeds the constant-current supply, input voltage will drop until U4 (APX810-44SA) switches off (VOUTF=4.4V). This will result in U4 cycling VCC with its 240ms delay. This threshold (which must be above max B+ (4.3V) to ensure U1 is unpowered when not charging) is above the VCC where U1 (BQ21040) will current throttle (<4.3V). As such, to charge, we require current consumption to always be below input current (allowing some to bias D2 (5.6V zener), maintaining the input voltage >4.4V), and thus the current setting needs to be conservative: ISET is 36.7~47.3mA (with range of KISET from BQ21040 datasheet, assuming no tolerance on resistors). Even this is marginal, as at the upper limit, +2.3mA for U1 + CHG LED, we might exceed available supply current. Add to this the HP supply is nominally 50mA, but in practice has tolerance - mine is measured at 49.5mA, but others may vary more. Currently assuming tolerance of +/-2mA, i.e. minimim 48mA, to design to a safe margin, the ISET may even need to be reduced.

If we could allow U1 to throttle, we could consume maximum available current for charging, regardless of the supply tolerance. Also, BQ21040 datasheet indicates that in this mode, the 10h timer is slowed to 20h, which would enable a 1000mAh or so per charge instead of only 500mAh. As such, it may be advantageous to encourage this mode rather than avoid it (in backfeed charge).

Testing using the USB input, I've worked out that BQ21040 will throttle well down to VCC=3.5V, and charge a nearly full cell (B+=4.1V) at VCC=4.5V, ICHG > 50mA. Ideally then VCC should be below VOUT, such that the throttling range for U1 (3.5~4.3V) corresponds to the backfeed voltage mode range for VOUTF (4.4~5.6V). A diode here would provide the drop. While it would prevent load sharing with USB input, for this design the USB is not accessible in-system so this is not required. Should an in-system alternative input (e.g. QI charging?) be added, this would require an alternative VCC input which diode feeds both VCC and VOUT (and U3 will take care of disconnecting B+ from load).

As B+ can be as low as 3.1V, we should assume VCC might drop close to this (even though datasheet says 3.5V min). As such, to avoid cycling V(diode) should be 4.4V-3.1V = 1.3V. This means, for excess current available, VOUT=5.6V, VCC = 4.3V, which is a bit close to the minimum for charging a full battery - would prefer 4.5V as tested - therefore 1.1V. [BAS116](https://assets.nexperia.com/documents/data-sheet/BAS116GW.pdf) has 1.1V at 50mA, which would be ideal.

Plan is to to a test on V3.5 board, and if this works, V5 will be updated to include the diode.

crozone, 2024-10-04:
Potentially outside the scope of this issue, but would this change allow compatibility with the USB to HP charging cables that are available on eBay?

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

They are implemented with a ~0.5V drop Schottky diode to drop the USB 5V to 4.5V for the logic supply, and a 68 ohm current limiting resistor for the charging circuit to give roughly the 40mA battery charging current. Would this be enough to maintain charging on the lipo?

grob6000, 2024-10-04:
Hi, thanks for providing the info on those cables! Yes, currently 40mA limit on the supply would likely cause this problem.

I built a test version using a 1N4148 and 9k1 R1 and it was quite happy charging even with about 25mA available, so I'd expect it would work with these cables.

For anyone with rev3.5 or earlier, you can cut the VCC track at the top of the board (runs between pin3 of Q2 and cathode of the USB diode), and solder a 4148 in there.

Currently working on an updated design (unregulated battery output only, which is demonstrably the better option for nearly all cases, with the new diode), so hang in there a week or so and it will be ready to go.

grob6000, 2024-10-15:
Implemented with v5: 30ffbc13f589585e5461ab38b471176c49de2603

Closed 2024-10-15.

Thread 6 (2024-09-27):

Simplification - unregulated only

grob6000, 2024-09-27:
The board is currently pretty dense for a 2-layer.

Considering eliminating the regulator: the regulator adds some idle current, and has limited benefit other than the small additional run time for HP35 only. The 4.3V potential maximum batttery voltage has been tested to work fine on a range of designs (35, 45, and 67). In fact, for the HP67, which has the card reader / amplifier IC permanently connect to battery (even during charging), the 5.6V zener clamp voltage has not caused any issue (the IC architecture is resistant to at least 6.5V it seems).

In my calculators, I've settled on the unregulated design being the preference.

I can split the design into two board layouts - one for regulated, one for unregulated, allowing more space for better layout (e.g. better thermal pads for easier assembly etc.).

grob6000, 2024-10-15:
Unregulated design only for v5: 30ffbc13f589585e5461ab38b471176c49de2603

Closed 2024-10-15.

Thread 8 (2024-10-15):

USBC

grob6000, 2024-10-15:
Considering an alternative USBC version, for those who want their 1974 calculator to be dragged into 2024 instead of 2004.

grob6000, 2024-10-28:
I did make a prototype board for this, albeit with some questionable design decisions at the time.

I like the idea of a USB-C cable/adapter board. Initially can be very simple, pretty much providing the 4.2V calculator supply and 50mA constant current supply for the battery charger.

To enable fast charging, I'd need some kind of signal between the charger to the calcpack. The charger could move to constant voltage and the calcpack increase the charge current (probably as per the current USB circuit). An interesting problem, would love any input but otherwise need some time to think about it.

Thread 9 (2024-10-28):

Tight fit in a HP35

grob6000, 2024-10-28:
One tester has reported the assembly is a tight fit in their HP35 - difficulty engaging the cover latches.

Consider reducing as far as practicable the case thickness/dimensions for the 2000mAh battery (10.5mm thick), otherwise the standard design will be reducing to 1500mAh capacity (8mm thick).

crozone, 2024-11-06:
Related, do you have a recommended PCB thickness for manufacturing these?

grob6000, 2024-11-06:
I use 1.6mm standard boards, but feel free to experiment with thinner. A
touch less thickness on the board may help here!

Alternatively, can always use a 8mm thick battery (and a thinner case;
uploading the model on my todo list).

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

grob6000, 2024-11-07:
Now added the 8mm battery case option. This is significantly thinner (1.5mm less), albeit will be limited to a ~1500mAh 803450 battery: 137d82596de65c59421a0eff91bd49e9d54f383c

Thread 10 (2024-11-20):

Mouser or Digikey saved basket for BOM?

crozone, 2024-11-20:
I'm currently building out the mouser shopping card for the v5 BOM and getting some choice paralysis on the generic parts.

Do you happen to have an existing saved basket for mouser or digikey? If not, should I build one out and submit it for future use?

grob6000, 2024-11-26:
Hi there! BOM has been refereshed with e6dfacf37bfa06bdd88ff2dee844c53cb2cf4b45, apologies for the confusion.

Happy to receive a link for a successful cart, otherwise I'll likely clean up my last Digikey BOM and provide a link in the readme.

grob6000, 2024-11-26:
Digikey shared list here: https://www.digikey.com.au/en/mylists/list/Z6K09H5IB0

crozone, 2024-11-27:
Thanks, this is a massive help! I'm currently working on a Mouser version as well. There's a few substitutions that I'll need to double check.

Closed 2024-11-26.

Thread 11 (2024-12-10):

Assembly notes and suggestions

crozone, 2024-12-10:
I've just finished building 5x of the v5 boards and have a few notes on the process:

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

## PCBs

I used JLCPCB for the PCB order, with solder paste stencil.

There was a small issue with getting the stencil cut which came up during the review. They flagged that the paste layer slightly overlaps the holes on the microUSB port layout, which would cause paste to enter the holes.

> "Shall we close (not expose) the holes in the middle on stencil to prevent solder tin from getting into the holes?"

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

I opted to have them close the holes and also expose the gold ring around the holes. I ended up just manually filling in these holes with solder using the iron as a final assembly step.

Another note: Specify the stencil size when ordering! If you don't, they send you an A3 sized stencil, which is comically large.

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

## BOM

I used the digikey list to order the parts which went super smoothy. Remember to remove R13 (10k) from the order if you're using 3 pin LiPos with built in thermistor, unless you want spares... :)

## Assembly

I have a few assembly notes from the process which might be helpful for others who are newer to SMT:

* The diode orientation is denoted on the main silkscreen around each diode with a three sided rectangle where the closed edge is the cathode and the open edge is the anode.
    * Maybe a note should be added to the "assembly notes" in the README for this convention.

* Similarly, there are parallel lines on either side of the ICs where one side is longer to indicate the location of pin 1. Some of them have a dedicated arrow, but some don't.

* The cathode indicator line is missing from D2, D4, and CHG on the silkscreen lower layout guide. This is obviously redundant once you can read the main silkscreen symbols but it would be nice to have and is included for D1.

* Similarly, U1 is missing the pin 1 corner indicator on the silkscreen lower layout guide, and it's the only IC on the board with ambiguous orientation.

* Some parts use a vertical line to denote the left side of the part where pin 1 is the lower left pin, such as on BQ21040DBVR (U1):
    * This is probably super obvious, I just hadn't seen it before. The datasheet doesn't mention it either and only shows the dot marking for pin 1.

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

* The LEDs have a tiny extra square on the underside to denote the cathode side, but check the datasheet since sometimes the manufacturers get it wrong and it's the wrong way around.

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

That's about it!

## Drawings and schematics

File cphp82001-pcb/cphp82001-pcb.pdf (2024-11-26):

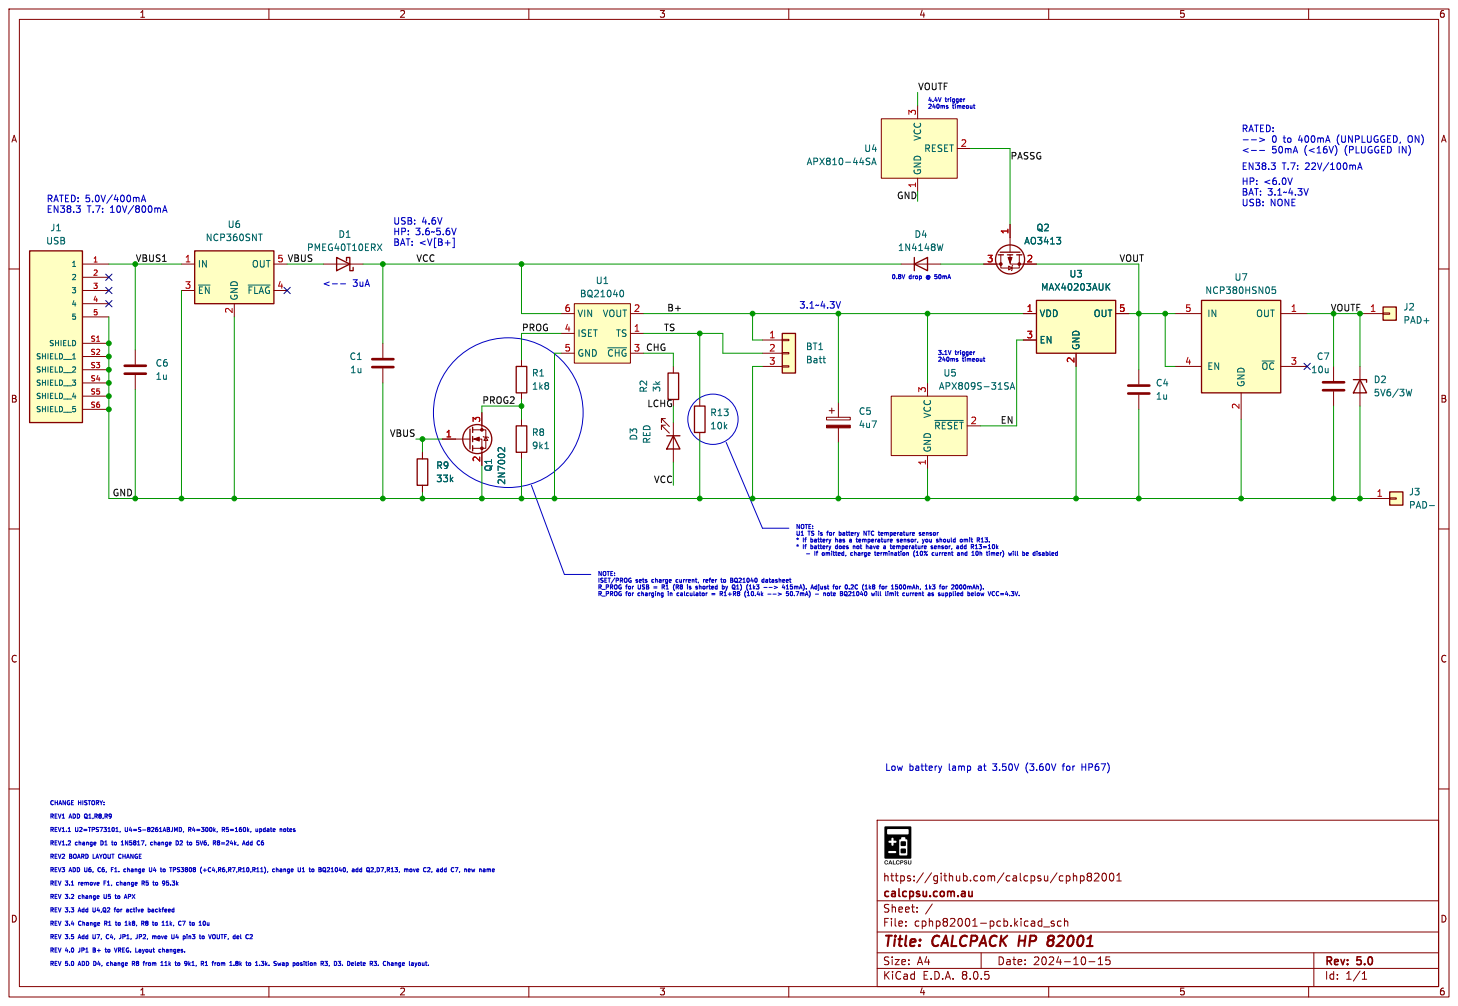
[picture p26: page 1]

Low battery lamp at 3.50V (3.60V for HP67)

https://github.com/calcpsu/cphp82001
File: cphp82001-pcb.kicad_sch Sheet: / calcpsu.com.au

Id: 1/1 Title: CALCPACK HP 82001

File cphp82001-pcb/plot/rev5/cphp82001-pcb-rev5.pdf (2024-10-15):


Low battery lamp at 3.50V (3.60V for HP67) NOTE:

https://github.com/calcpsu/cphp82001
File: cphp82001-pcb.kicad_sch Sheet: / calcpsu.com.au

Id: 1/1 Title: CALCPACK HP 82001

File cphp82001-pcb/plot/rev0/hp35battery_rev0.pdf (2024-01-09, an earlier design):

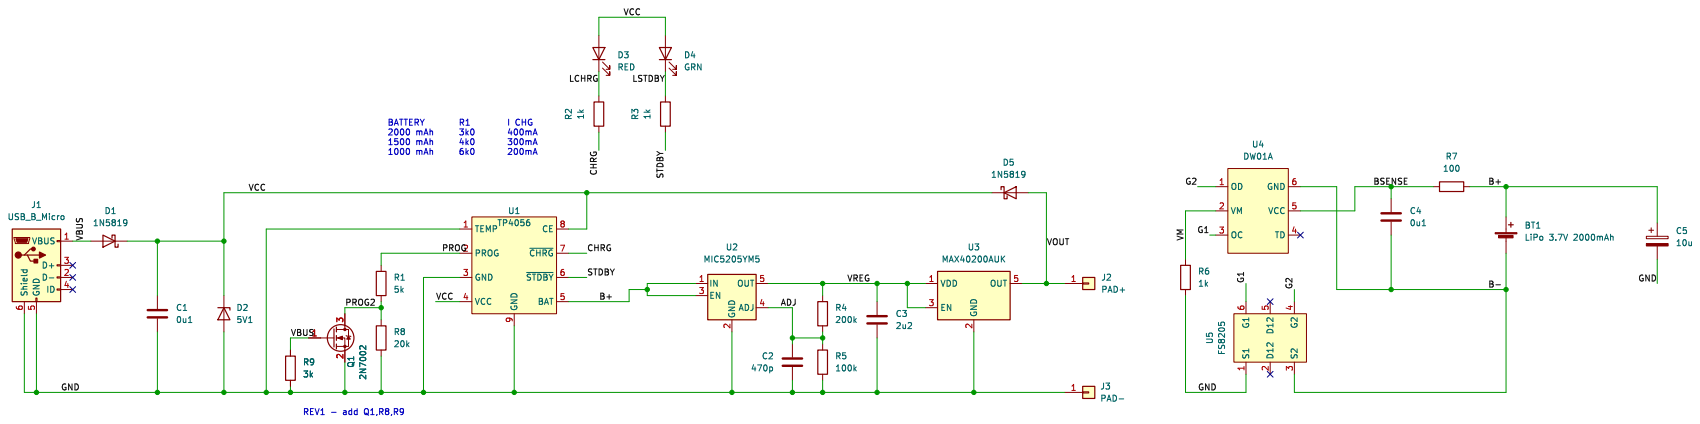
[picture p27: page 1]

Id: 1/1 Title: HP BATTERY

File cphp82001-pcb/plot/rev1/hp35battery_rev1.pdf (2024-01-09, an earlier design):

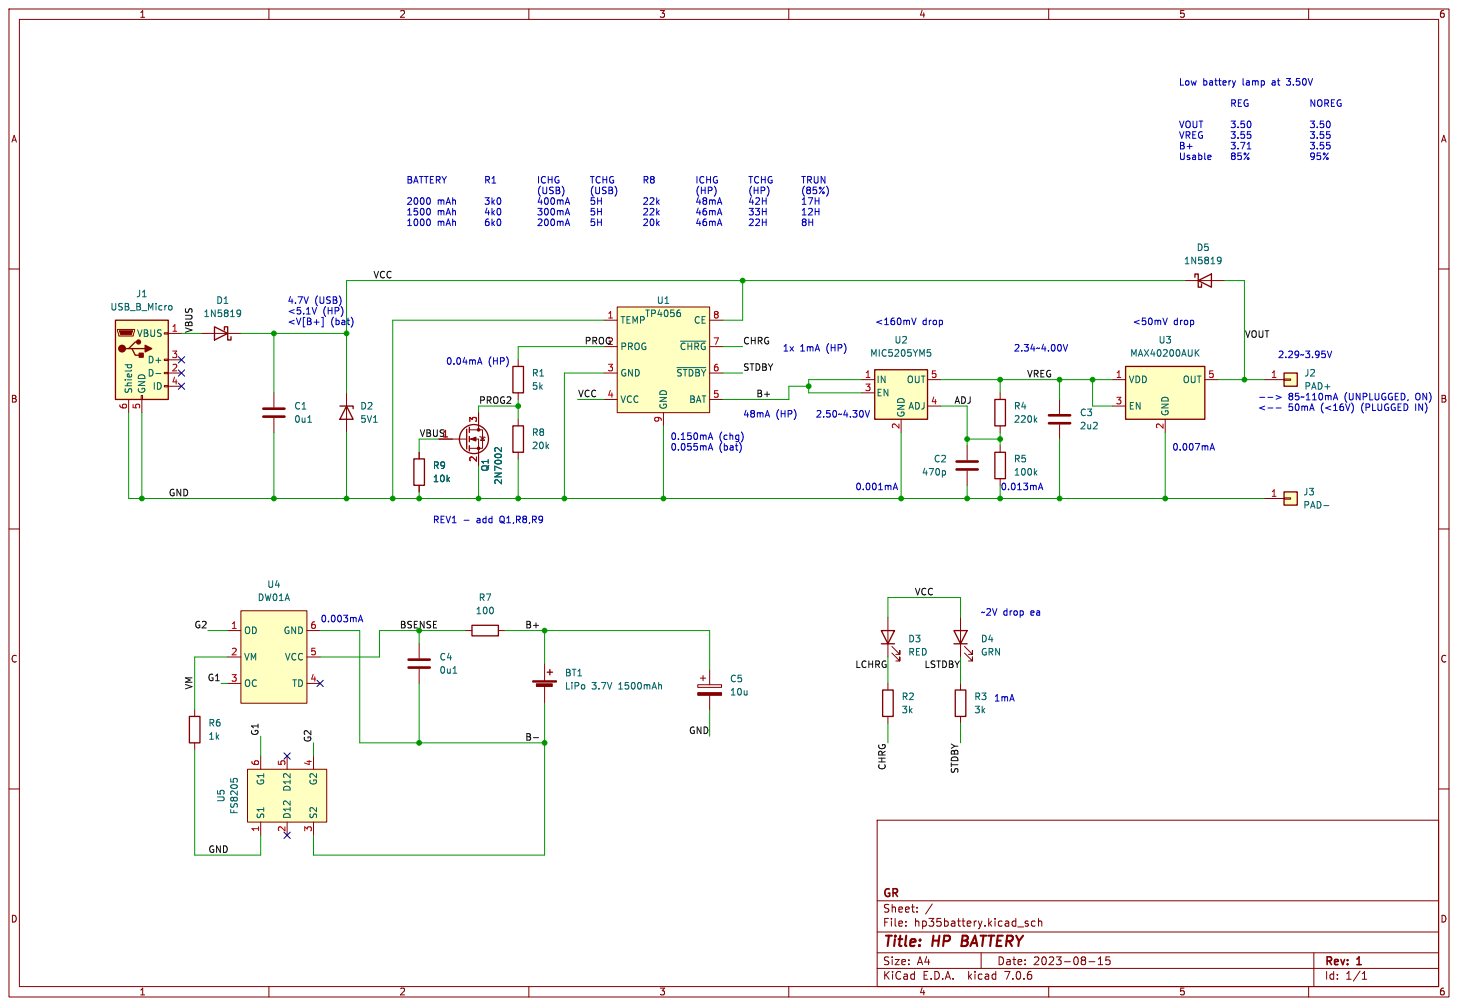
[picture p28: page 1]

Low battery lamp at 3.50V REG NOREG

0.04mA (HP) BATTERY R1 ICHG TCHG R8 ICHG TCHG TRUN
(USB) (USB) (HP) (HP) (85%) 2000 mAh 3k0 400mA 5H 22k 48mA 42H 17H

9 U1 TP4056 D3 RED OD 1 VM 2 OC 3 TD 4 VCC 5 GND 6 U4 DW01A

Id: 1/1 Title: HP BATTERY

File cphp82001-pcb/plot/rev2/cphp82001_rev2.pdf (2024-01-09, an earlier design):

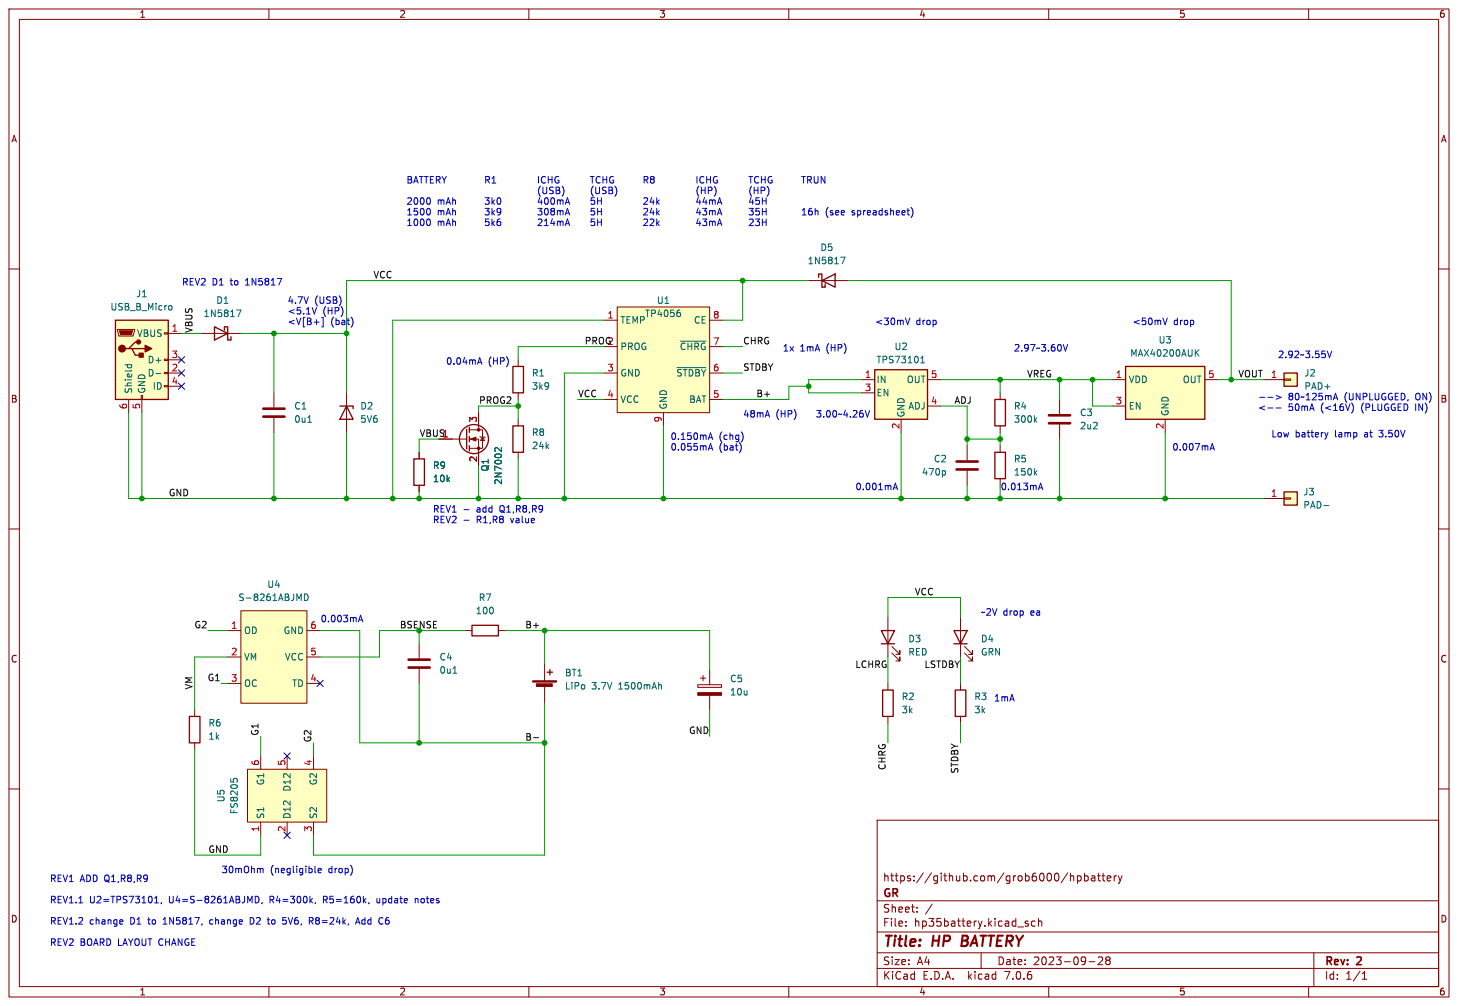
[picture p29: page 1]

BATTERY R1 ICHG TCHG R8 ICHG TCHG TRUN
(USB) (USB) (HP) (HP) 2000 mAh 3k0 400mA 5H 24k 44mA 45H
VREG CHRG
ADJ VCC

Low battery lamp at 3.50V

https://github.com/grob6000/hpbattery
File: hp35battery.kicad_sch Sheet: / GR

Id: 1/1 Title: HP BATTERY

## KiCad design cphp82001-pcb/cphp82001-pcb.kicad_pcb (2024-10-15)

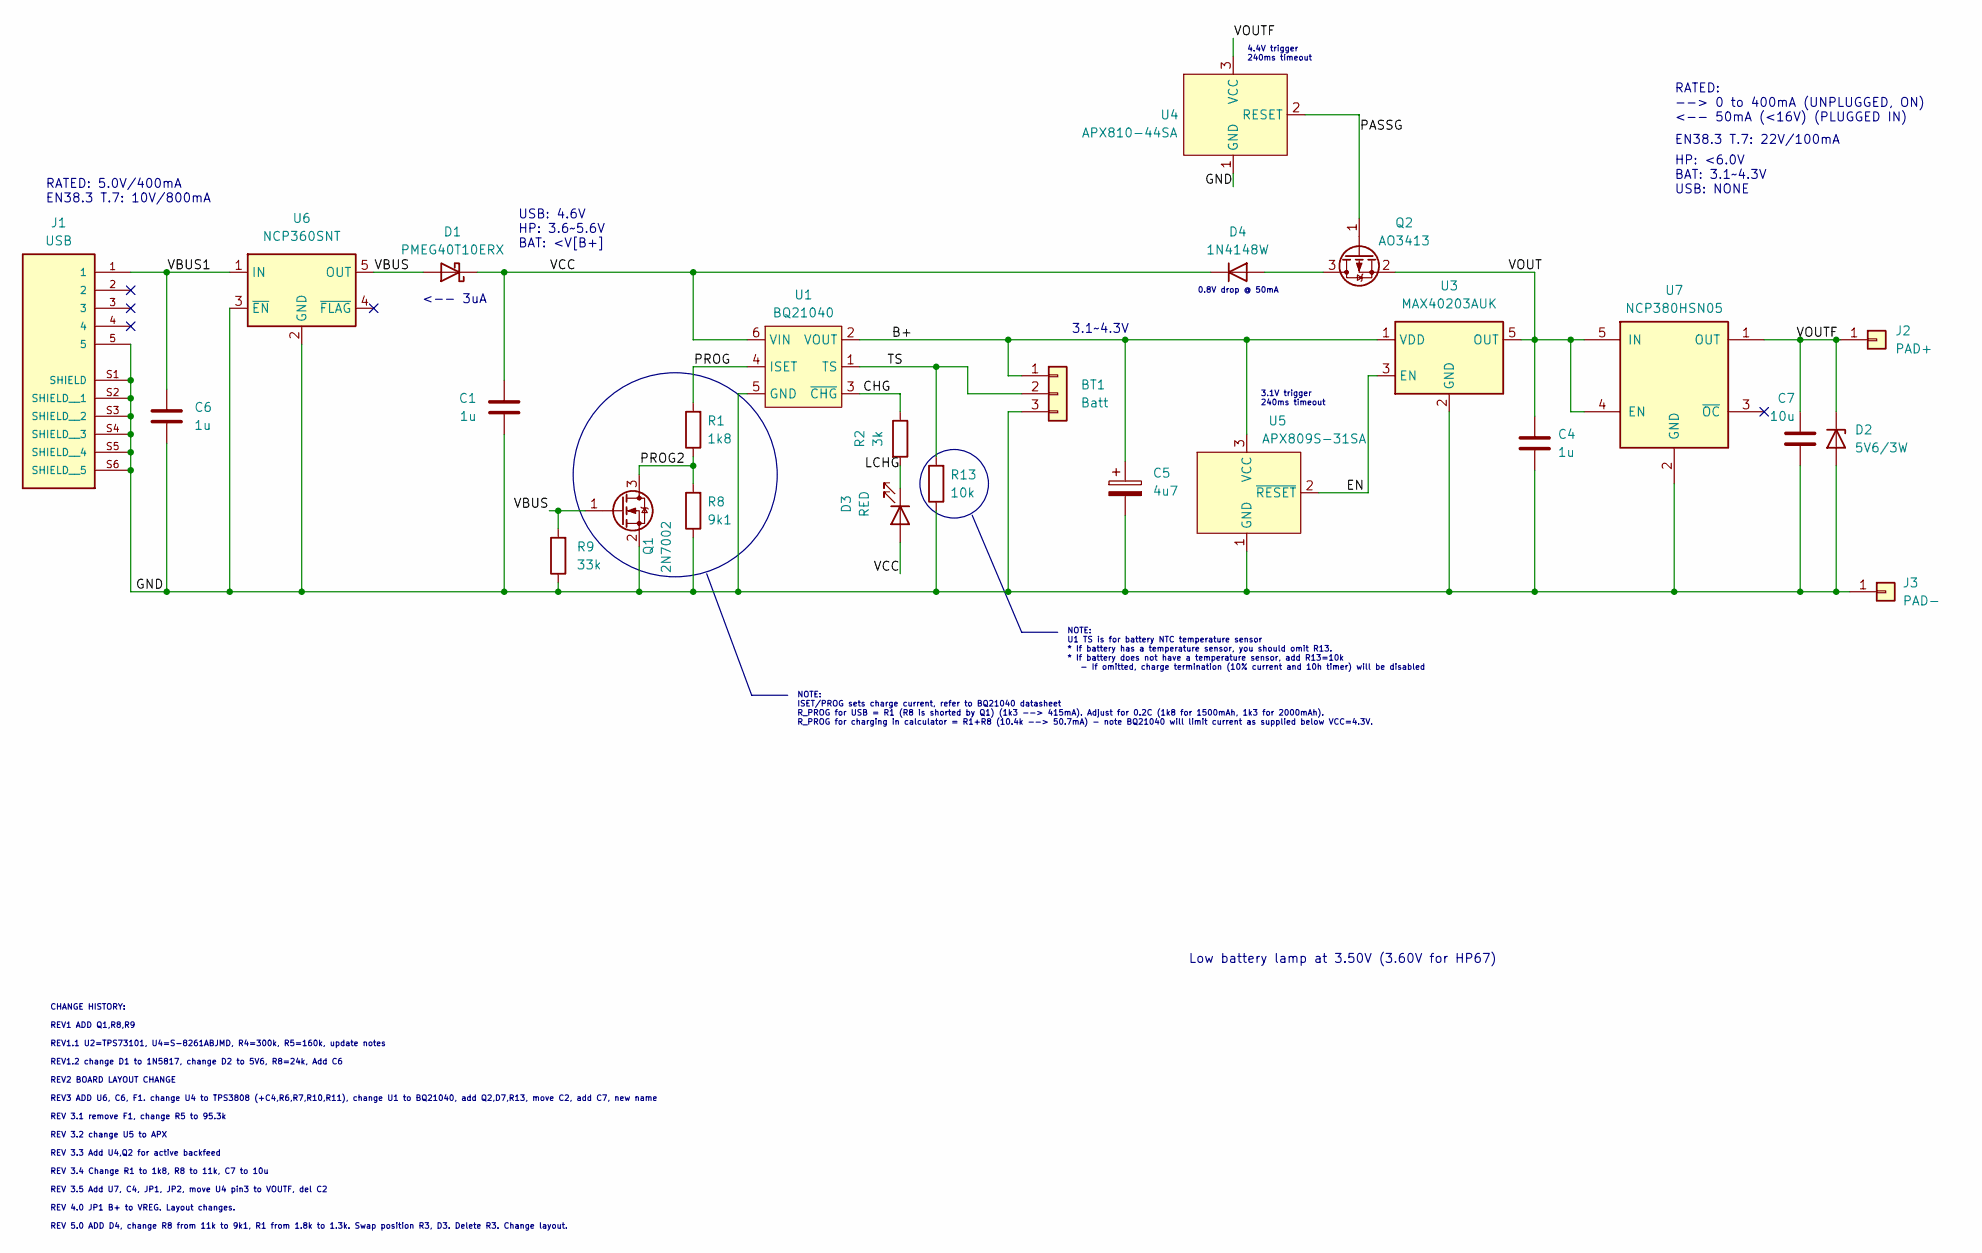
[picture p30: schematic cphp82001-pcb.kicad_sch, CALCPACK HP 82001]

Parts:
BT1: Batt; JST_SH_BM03B-SRSS-TB_1x03-1MP_P1.00mm_Vertical_13PADS
C1, C4, C6: 1u; C_0805_2012Metric
C5: 4u7; C_0805_2012Metric
C7: 10u; C_0805_2012Metric
D1: PMEG40T10ERX; D_SOD-123
D2: 5V6/3W; D_SMA
D3: RED; LED_0805_2012Metric
D4: 1N4148W; D_SOD-123
J1: USB; AMPHENOL_10118194-0001LF; PARTREV D
J2: PAD+; PAD_8x15
J3: PAD-; PAD_8x15
Q1: 2N7002; SOT-23
Q2: AO3413; SOT-23
R1: 1k8; R_0805_2012Metric
R2: 3k; R_0805_2012Metric
R8: 9k1; R_0805_2012Metric
R9: 33k; R_0805_2012Metric
R13: 10k; R_0805_2012Metric
U1: BQ21040; SOT-23-6_TI_DBV6
U3: MAX40203AUK; SOT-23-5_TI_DBV5
U4: APX810-44SA; SOT-23-3
U5: APX809S-31SA; SOT-23-3
U6: NCP360SNT; SOT-23-5_TI_DBV5
U7: NCP380HSN05; SOT-23-5_TI_DBV5

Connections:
/B+: BT1.1, C5.1, U1.2 (VOUT), U3.1 (VDD), U5.3 (VCC)
/CHG: R2.1, U1.3 (~CHG)
/EN: U3.3 (EN), U5.2 (~RESET)
/GND: BT1.3, C1.2, C4.2, C5.2, C6.2, C7.2, D2.2 (A), J1.5, J1.S1 (SHIELD), J1.S2 (SHIELD__1), J1.S3 (SHIELD__2), J1.S4 (SHIELD__3), J1.S5 (SHIELD__4), J1.S6 (SHIELD__5), J3.1, Q1.2 (S), R8.1, R9.1, R13.1, U1.5 (GND), U3.2 (GND), U4.1 (GND), U5.1 (GND), U6.2 (GND), U6.3 (~EN), U7.2 (GND)
/LCHG: D3.1 (K), R2.2
/PASSG: Q2.1 (G), U4.2 (RESET)
/PROG: R1.2, U1.4 (ISET)
/PROG2: Q1.3 (D), R1.1, R8.2
/TS: BT1.2, R13.2, U1.1 (TS)
/VBUS: D1.2 (A), Q1.1 (G), R9.2, U6.5 (OUT)
/VBUS1: C6.1, J1.1, U6.1 (IN)
/VCC: C1.1, D1.1 (K), D3.2 (A), D4.1 (K), U1.6 (VIN)
/VOUT: C4.1, Q2.2 (S), U3.5 (OUT), U7.4 (EN), U7.5 (IN)
/VOUTF: C7.1, D2.1 (K), J2.1, U4.3 (VCC), U7.1 (OUT)
unnamed: D4.2 (A), Q2.3 (D)

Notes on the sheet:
<-- 3uA
NOTE: ISET/PROG sets charge current, refer to BQ21040 datasheet R_PROG for USB = R1 (R8 is shorted by Q1) (1k3 --> 415mA). Adjust for 0.2C (1k8 for 1500mAh, 1k3 for 2000mAh). R_PROG for charging in calculator = R1+R8 (10.4k --> 50.7mA) - note BQ21040 will limit current as supplied below VCC=4.3V.
HP: <6.0V BAT: 3.1~4.3V USB: NONE
EN38.3 T.7: 22V/100mA
3.1V trigger 240ms timeout
RATED: --> 0 to 400mA (UNPLUGGED, ON) <-- 50mA (<16V) (PLUGGED IN)
USB: 4.6V HP: 3.6~5.6V BAT: <V[B+]
3.1~4.3V
NOTE: U1 TS is for battery NTC temperature sensor * If battery has a temperature sensor, you should omit R13. * If battery does not have a temperature sensor, add R13=10k - If omitted, charge termination (10% current and 10h timer) will be disabled
4.4V trigger 240ms timeout
RATED: 5.0V/400mA EN38.3 T.7: 10V/800mA
0.8V drop @ 50mA
CHANGE HISTORY: REV1 ADD Q1,R8,R9 REV1.1 U2=TPS73101, U4=S-8261ABJMD, R4=300k, R5=160k, update notes REV1.2 change D1 to 1N5817, change D2 to 5V6, R8=24k, Add C6 REV2 BOARD LAYOUT CHANGE REV3 ADD U6, C6, F1. change U4 to TPS3808 (+C4,R6,R7,R10,R11), change U1 to BQ21040, add Q2,D7,R13, move C2, add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
Low battery lamp at 3.50V (3.60V for HP67)

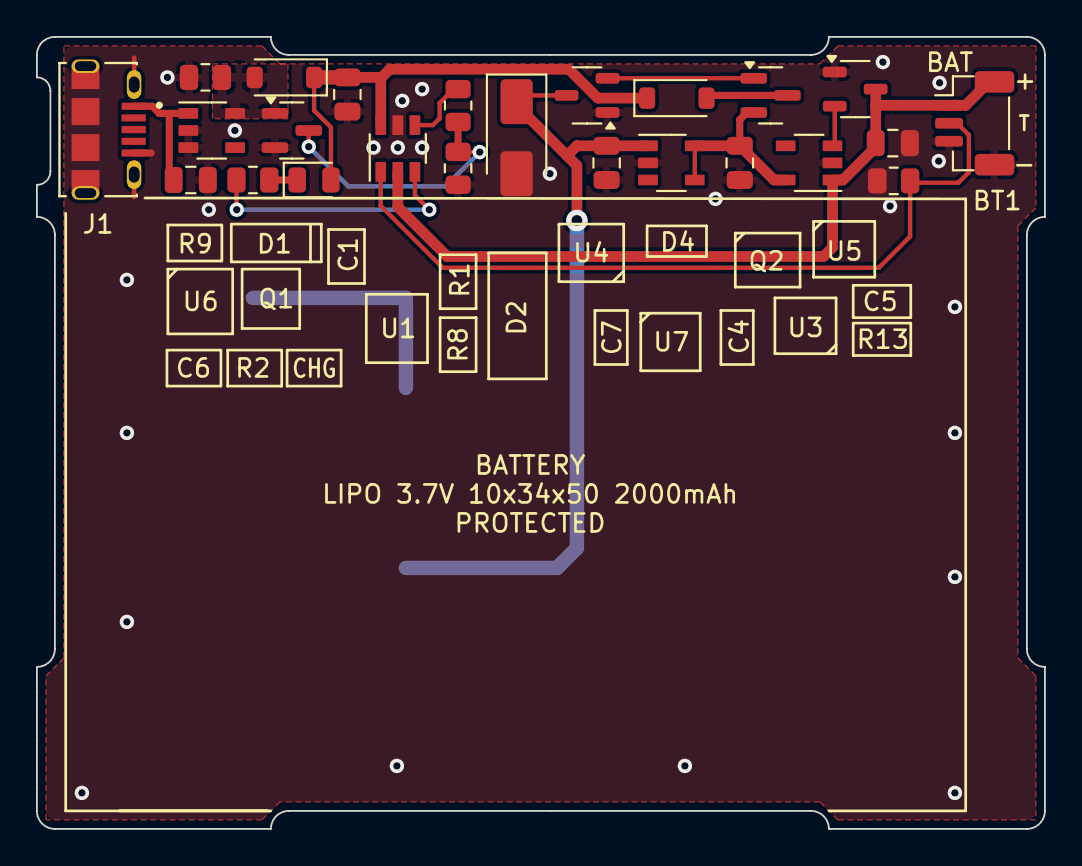
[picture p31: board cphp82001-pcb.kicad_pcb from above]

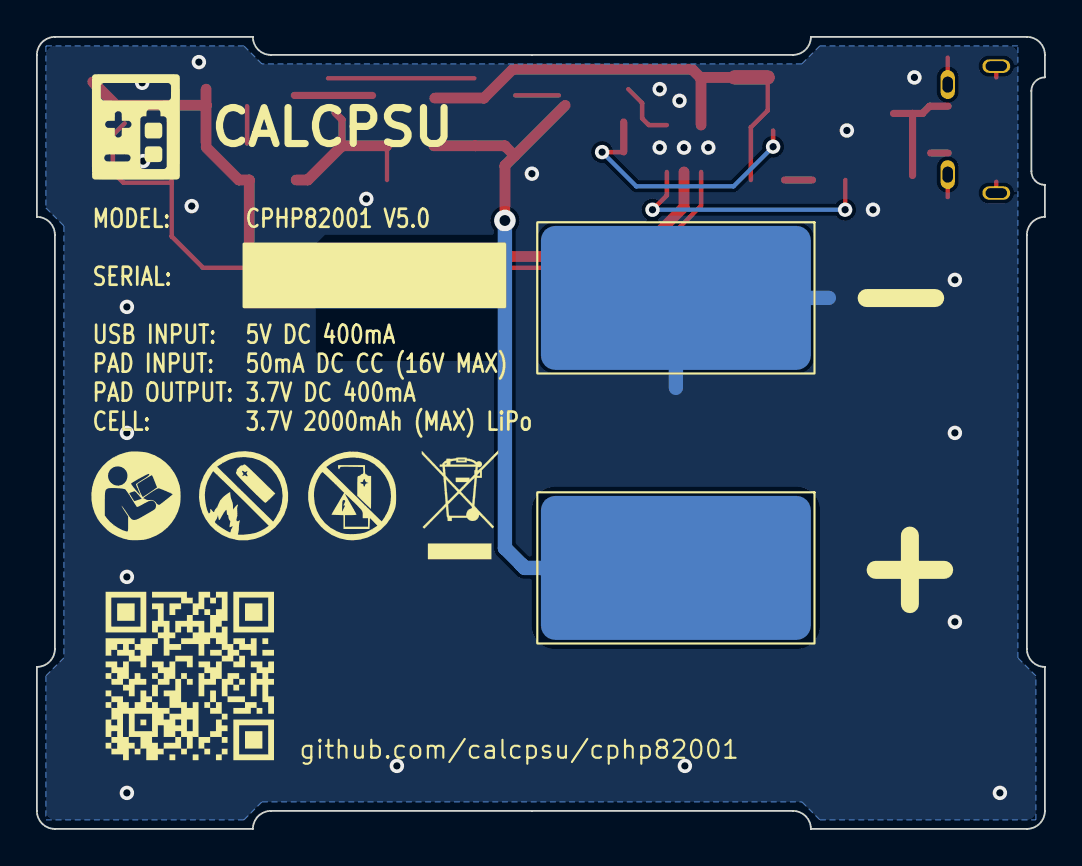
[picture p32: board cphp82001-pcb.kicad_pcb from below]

Board: 2 copper layers, 56.0 x 44.0 mm, 26 parts (2 on the bottom side), 15 nets.

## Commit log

2024-01-09 rev3 pcb
    [BM02B-SRSS-TB.STEP, BM03B-SRSS-TB.STEP, CDRN74.stp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]
2024-01-09 add docs
    [cphp82001.xlsx]
2024-01-09 old board revisions - plots and schematics
2024-01-09 move schematic to plot (rev2)
2024-01-09 move old plots to pcb folder
2024-01-09 plot rev3
    [cphp82001-pcb-B_Cu.gbr, cphp82001-pcb-B_Mask.gbr, cphp82001-pcb-B_Paste.gbr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]
2024-01-10 move component 3d models to pcb folder
    [BM02B-SRSS-TB.STEP, BM03B-SRSS-TB.STEP, CDRN74.stp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]
2024-01-10 Update rev3
    [cphp82001-pcb.kicad_pcb, cphp82001-pcb.kicad_sch]
2024-01-10 Export 3d step file pcb
2024-01-10 Plot rev3.1
    [cphp82001-pcb-B_Cu.gbr, cphp82001-pcb-B_Mask.gbr, cphp82001-pcb-B_Paste.gbr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]
2024-01-12 board layout update
    [cphp82001-pcb.kicad_sch]
2024-01-12 Updates to model
    [cphp82001-pcb.kicad_sch, cphp82001.xlsx]
2024-01-14 Update power model
2024-01-15 Update board and render (v3.1)
    [cphp82001-pcb.kicad_pcb, cphp82001-pcb.kicad_sch]
2024-01-15 A few more updates (v3.1)
    [cphp82001-pcb-B_Cu.gbr, cphp82001-pcb-B_Mask.gbr, cphp82001-pcb-B_Paste.gbr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]
2024-01-29 rev3.3 final
    [cphp82001-pcb-B_Cu.gbr, cphp82001-pcb-B_Mask.gbr, cphp82001-pcb-B_Paste.gbr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]
2024-01-29 Update model for Iq
    [cphp82001.xlsx]
2024-04-16 Minor update
    [cphp82001-pcb.kicad_sch]
2024-09-09 Update case 3d files
    [cphp82001_case.step, cphp82001_case.stl, hpbatterycase_07.stl]
2024-09-24 Rev 4.0
    [cphp82001-pcb-B_Cu.gbr, cphp82001-pcb-B_Mask.gbr, cphp82001-pcb-B_Paste.gbr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]
2024-09-24 Update schematic notes
    [cphp82001-pcb.kicad_sch]
2024-09-25 Update to charge termination R13 instructions
    [cphp82001-pcb.kicad_sch]
2024-09-25 Amend instructions after testing
    [cphp82001-pcb.kicad_sch]
2024-09-26 Amend BOM
    Misaligned with
    [cphp82001-pcb-bom.xlsx, cphp82001-pcb.csv]
2024-09-26 Missing files from power model
    [battery.csv, efficiency_mic2250.csv, ignd_tlv75801.csv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]
2024-11-07 add 8mm case option
    [cphp82001_case_10mm.step, cphp82001_case_10mm.stl, cphp82001_case_8mm.step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]
2024-11-26 Updated BOM
    [cphp82001-pcb.csv, cphp82001_pcb_bom.csv]
2025-02-19 Minor update to BOM
    [cphp82001-pcb.csv]
2025-02-19 Refresh 3D file
    [cphp82001-pcb.step]
2025-02-19 Minor change to case
    Add cutout to enable v3.5 diode modification (v3.5A).
    [cphp82001_case_10mm.step, cphp82001_case_8mm.step, cphp82001_case_led_10mm.step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]
